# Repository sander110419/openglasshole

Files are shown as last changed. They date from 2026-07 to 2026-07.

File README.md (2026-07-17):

# OpenGlassHole

An open-source, clip-on, monocular heads-up autocue for ordinary prescription glasses.
It uses a tiny Wi-Fi microcontroller, a 64×32 white OLED, one positive lens, and
a separate 45° combiner pane to put scrolling server text at a comfortable
virtual distance. The reference optical path uses the OLED's central 48×32
pixels to trade two characters per line for a larger eye box.

OpenGlassHole optical path

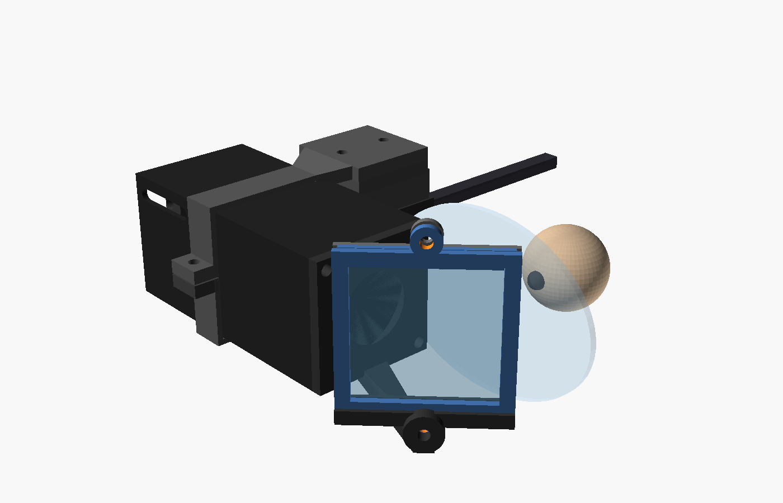
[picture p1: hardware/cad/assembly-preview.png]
OpenGlassHole right-eye CAD assembly preview


*CAD packaging preview, not a photograph or physical fit validation.*

> **Prototype status:** firmware, server, schematic, and parametric CAD are
> implemented and build-checked, but this v0.1 hardware has not yet been
> physically assembled or optically validated. Dimensions, runtime, eye box,
> and comfort are engineering targets until a real build report lands.

## The honest version

- **Budget-reference known cost:** **$46.59 USD** (prices checked 2026-07-17),
  using linked major parts and
  consumable allowances in [hardware/bom.csv](hardware/bom.csv). The exact
  splitter listing includes delivery; other shipping, tax, tools, and the cost
  of buying full fastener/strap/filament packs remain unresolved, so this does
  **not** prove a delivered-under-$50 first build.
- **Electronics:** Seeed XIAO ESP32-C3, USB-C, 2.4 GHz Wi-Fi, onboard 1S LiPo
  charger, protected PKCELL 500 mAh cell, and a 0.49-inch Waveshare SSD1315
  OLED.
- **Optics:** a 25 mm / 45 mm FL positive lens and a 30×30 mm 50R/50T plate
  combiner. The pane—not the prescription lens—reflects the cue. A measured
  6×6 mm full-cue eye box is a build acceptance requirement, not a promise.
- **Expected use:** seated, stationary, indoor autocue. It will wash out in
  sunlight and has a much smaller eye box than commercial waveguide glasses.
- **Power target:** roughly 18–29 hours with 15-second radio-off polling and
  sparse low-contrast text; about 4.2 hours is the conservative sustained
  worst-case estimate. Neither is a measured runtime yet.
- **Packaging:** the printed forward assembly's CAD envelope is about
  89.2×61.1×46.4 mm (the tunnel itself is 58.8×27.9×27.9 mm). With the optional
  rear pod on the glasses, the full envelope is about 113.5×120.3×46.4 mm. A
  preliminary all-on-glasses mass estimate is roughly 55–65 g; use the
  documented collar/pocket-pod option if that is uncomfortable. Neither mass
  nor comfort has been measured on a real build.

The focus sled, padded strap saddle, sliding rail, separate rear electronics
pod, left/right assembly previews, bench jig, and combiner cut template are
parametric. The OLED driver pre-mirrors text and handles the module's
nonstandard visible RAM-column offset.

## Safety first

This is uncertified DIY eyewear, not PPE or a medical device. Never use it while
driving, cycling, crossing roads, walking in traffic, using stairs, or operating
machinery. Charge the LiPo off-head and attended; never wear exposed prototypes.
The positive lens can concentrate sunlight, and every glass edge must be fully
captured. Read [the complete safety rules](docs/SAFETY.md) before ordering parts.

## How it works

```text
phone/browser ──PUT──> tiny Python cue server
                             │
                        conditional GET
                             │ Wi-Fi every ~15 s
                             ▼
                   XIAO ESP32-C3 ─I²C─> OLED
                                           │
eye <─ prescription lens <─ combiner <─ collimating lens
```

The server returns raw cue text plus `ETag`, poll, and scroll headers. Unchanged
cues return `304` with no body. The display caches the last valid cue, turns the
radio off between polls, word-wraps it to 8 characters × 4 rows, and
scrolls upward through network outages. The first and last views pause briefly
before the cue loops. Tap the one button to pause/resume; hold it to fetch
immediately.

## Build it

1. Read [SAFETY.md](docs/SAFETY.md), then inspect the
   [BOM](hardware/bom.csv) and [power assumptions](docs/POWER.md).
2. Wire the OLED over USB only using the
   [schematic](hardware/electronics/schematic.svg).
3. Copy `firmware/include/config.example.h` to the gitignored `config.h`, set
   Wi-Fi/server values, then build and flash with PlatformIO.
4. Run the dependency-free server:

   ```sh
   export OPENGLASSHOLE_API_KEY='replace-with-a-long-random-key'
   python3 server/cue_server.py --host 0.0.0.0 --port 8787
   ```

5. Print the fit coupon and focus jig. Prove focus and brightness on the bench
   before printing or wearing the clip.
6. Follow the [full build and alignment guide](docs/BUILD_GUIDE.md).

The browser editor is at `http://<server-lan-ip>:8787/`. The firmware consumes
`/api/v1/cue.txt?device=default`; see [API.md](docs/API.md) for automation.

## Repository map

| Path | Contents |
| --- | --- |
| [`firmware/`](firmware/) | PlatformIO XIAO firmware and custom 0.49-inch SSD1315 driver |
| [`server/`](server/) | Dependency-free Python cue API, editor, persistence, and tests |
| [`hardware/cad/`](hardware/cad/) | Parametric OpenSCAD, export tooling, and printable releases |
| [`hardware/electronics/`](hardware/electronics/) | Wiring schematic and assembly checks |
| [`hardware/bom.csv`](hardware/bom.csv) | Linked major parts, consumable allowances, and the <$50 calculation |
| [`docs/OPTICS.md`](docs/OPTICS.md) | Optical design, calculations, focus, and combiner tradeoffs |
| [`docs/BUILD_GUIDE.md`](docs/BUILD_GUIDE.md) | End-to-end print, wire, focus, mount, and test procedure |

## Validate the source

```sh
python3 -m unittest discover -s server/tests -v
python3 tools/check_bom.py
pio run --project-dir firmware
make -C hardware/cad check-release
python3 tools/check_repo.py
```

The software build does not prove optical focus, OLED brightness, battery
runtime, LiPo safety, fit, or comfort. A first physical build should record each
item in the acceptance checklist and the
[build-report template](docs/BUILD_REPORT_TEMPLATE.md) rather than silently
changing the design.

## Design references

- [Seeed XIAO ESP32-C3 dimensions, charging, pins, and power](https://wiki.seeedstudio.com/XIAO_ESP32C3_Getting_Started/)
- [Waveshare 0.49-inch SSD1315 OLED specifications](https://www.waveshare.com/0.49inch-oled-module.htm)
- [Espressif ESP32-C3 current specifications](https://documentation.espressif.com/esp32-c3_datasheet_en.pdf)
- [CERN Open Hardware Licence v2](https://cern-ohl.web.cern.ch/)

## License

Software is MIT licensed. Hardware, CAD, schematics, and build documentation are
licensed under CERN-OHL-P-2.0. See [LICENSE](LICENSE) for the exact scope and
notices. Third-party components and libraries retain their own licenses.

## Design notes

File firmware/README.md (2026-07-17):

# Firmware

This PlatformIO project targets the Seeed Studio XIAO ESP32-C3 and the exact
Waveshare 0.49-inch 64×32 SSD1315 I²C module used by the reference CAD.

## Flash it

1. Install [PlatformIO](https://platformio.org/install).
2. Copy `include/config.example.h` to `include/config.h`.
3. Set the Wi-Fi SSID/password and the cue server's LAN URL in `config.h`.
4. Connect the XIAO over USB-C and run:

   ```sh
   pio run --target upload
   pio device monitor
   ```

The display downloads `cue.txt` with a conditional HTTP GET, caches the last
valid cue in flash only when it changes, then word-wraps and scrolls it with the
radio off. The reference optical build uses the central 48 columns at the
reference 5×7 font size, so text wraps to 8 columns × 4 rows. Words wrap at
spaces, words longer than 8 characters split safely, and
explicit line/paragraph breaks are retained. Cues of four wrapped rows or less
remain centered and static. Longer cues hold the first view for 1.2 seconds,
move upward one pixel per `scroll_ms`, hold the final four rows for 1.8 seconds,
then loop back to the beginning.

Long-press the optional D2 button to fetch immediately; tap it to pause/resume
without stopping background fetches. A changed cue restarts at its first view.
Set `FETCH_ON_BOOT_ONLY=true` to fetch a prepared script once and reconnect only
on a long press.

The custom display driver matters: the Waveshare module exposes controller
columns `0x20..0x5f`. A generic 64×32 SSD1306 library that writes columns
`0..63` can compile successfully yet show a blank panel.

Plain HTTP is for a trusted LAN only. HTTPS requires a root CA, checks the
certificate chain/hostname, bounds the handshake, and sends a bearer value only
over TLS. The pinned Arduino-ESP32 build does **not** validate certificate dates,
however, so this is not a hardened public-internet client. Prefer a private LAN
or VPN and do not expose the bundled server directly.

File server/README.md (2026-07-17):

# Cue server

`cue_server.py` is a dependency-free Python 3.11+ threaded HTTP server with:

- a responsive browser cue editor at `/`
- minimal `GET /api/v1/cue.txt?device=...` responses with ETag/304 support
- JSON `GET` and authenticated text/JSON `PUT` endpoints
- per-device cues with fallback to `default`
- bounded inputs and atomic JSON persistence
- no API-key logging and no third-party package installation

Run on localhost for development:

```sh
OPENGLASSHOLE_API_KEY='development-only' python3 server/cue_server.py
```

Run on a trusted LAN for the glasses:

```sh
OPENGLASSHOLE_API_KEY='replace-with-a-long-random-key' \
  python3 server/cue_server.py --host 0.0.0.0 --port 8787
```

Test from the repository root:

```sh
python3 -m unittest discover -s server/tests -v
```

Read [the API and security model](../docs/API.md) before putting it on any
network other than a trusted LAN.

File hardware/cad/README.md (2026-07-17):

# OpenGlassHole CAD

This directory contains the parametric OpenSCAD 2021.01 source, reviewed STL
exports, and mechanical validation tools for the v0.1 monocular autocue. It is
a buildable optical/mechanical experiment, not certified eyewear. Prove the
optics on the bench before putting any part near an eye.

Wearable assembly preview with the optional rear pod hidden

## Presets and optical limits

`lens_preset="budget_25x45"` is the source and release-STL default:

- sourced 25 mm diameter, +45 mm focal-length biconvex acrylic lens;
- published 1.2 mm **edge** thickness, provisional 5 mm centre thickness and
  provisional, separately entered 1.90 mm crown sag on each face;
- explicit provisional packaging/focus-start datum 0.6 mm behind the front rim
  plane; this is not inferred from lens symmetry or claimed as a principal plane;
- 38–52 mm OLED focus travel, previewed at 45 mm;
- central 48×32 pixels of the 64×32 OLED (7.44×4.96 mm active viewport);
- conservative 15 mm physical aperture stop;
- 30×30×1.1 mm 50R/50T plate at 45 degrees, with 28 mm frame opening;
- 15 mm nominal lens-to-combiner axial gap and 32 mm bench eye datum.

`compact_23x30` remains available in source for experiments, but it is not a
recommended or release preset. At the same 32 mm eye datum its 10 mm stop and
wider field cannot provide a useful common full-viewport eye box. Do not buy the
more expensive compact lens on the assumption that it is a drop-in upgrade.

The SCAD computes the first-order extrema where the aperture/field rays meet an
oblique 45-degree pane. It also shifts the physical pane along its own axis to
centre that asymmetric footprint. For the budget preset the modeled footprint
is about 24.89 mm wide and the signed frame shift is about -1.03 mm, leaving
about 1.55 mm per side in the 28 mm opening. This calculation is deliberately
not presented as a guarantee: the physical stop is on the OLED side of a thick,
cheap singlet, and real principal planes, aberrations, decentre, and surface
tolerances matter. The focus bench and eye-box mapping are authoritative.

The modeled ray plane is the combiner's incoming/coated glass face, not the
printable base. The frame base is shifted 2.7 mm behind that face along the
pane normal, and each bracket/bench socket is centred on the complete 4.25 mm
base–glass–gap–clamp stack. This datum distinction prevents the plastic stack
from silently moving the reflected ray.

The best-case first-order common eye box at 15+32 mm propagation is only about
7.2 mm horizontal by 9.8 mm vertical for the budget preset. Treat that as an
optimistic estimate. Reject or redesign a build if the mapped eye box is not
comfortable; do not compensate by placing glass closer to the eye.

## Safe lens cell

The biconvex lens is not trapped between flat 15 mm rings. The tunnel has:

- full-diameter relief around both curved lens surfaces;
- three rear printed lands near the physical outer rim;
- three matching front lands on `lens_retainer` or `combiner_bracket`;
- a 15 mm tapered stop on the exterior/image-side front plate;
- a final 1.0 mm full-pocket counterbore before the compliant lands.

The SCAD takes `LENS_FRONT_SAG` and `LENS_REAR_SAG` as independent measured
inputs and derives a separate spherical envelope from each. The symmetric
1.90 mm defaults are provisional packaging data only. An asymmetric biconvex
lens may put most of its crown on either face. The stop-facing/image-side
**front** sag alone drives the analytic hard-gap check across the complete
taper; the rear sag alone drives the tunnel relief depth. The minimum need not
occur at the 15 mm aperture edge. With the provisional defaults, the true
minimum is about 1.012 mm at radius 11.036 mm for the budget lens and 0.855 mm
at radius 7.965 mm for the compact lens. Both exceed the asserted 0.6 mm
minimum, but neither is a guarantee for a purchased lens.

Before printing the final cell, measure the real lens in this order:

1. Measure diameter, centre thickness, and outer-rim edge thickness without
   squeezing the acrylic.
2. Support one rim plane on a depth-gauge fixture, measure its crown height,
   flip the lens, and independently measure the other crown height.
3. Confirm `edge + front sag + rear sag` agrees with centre thickness within
   the named 0.20 mm measurement allowance. Mark the face chosen to point at
   the retainer/combiner as **front/image-side** on removable rim tape.
4. Enter both measured sags and thicknesses, regenerate, and inspect the
   physical cell for at least 0.6 mm hard-surface clearance. The derived
   spherical surfaces are still approximations; the focus bench and a physical
   no-contact inspection are authoritative.

Put a matched nominal 0.7–0.8 mm closed-cell silicone, TPU, or optical-foam dot
on each of the six lands. Each opposing pair must exceed 1.2 mm uncompressed
(normally 1.4–1.6 mm total) and compress lightly into that modeled allowance;
reject a pair that rattles or requires plate bowing. Trim every dot so it
contacts only the outermost lens rim. Tighten the two front screws evenly only
until the dots prevent rattle. Printed plastic must never touch or preload
either convex clear surface.

## Combiner retention

Use the purchased square 30×30×1.1 mm glass plate as supplied. Do **not** score,
grind, chamfer, drill, or round the coated glass. The rounded/chamfered
`cut_template` is only for machinable plastic/film experiments or a professional
vendor-cut alternative. Mark coating orientation on removable frame tape, not
by modifying the pane.

The base's four overlapping full-length rails define a 32.0 mm rigid cavity;
they must never touch bare glass. Fit `combiner_edge_liner` around all four
edges and corners first. It is a one-piece **soft TPU or silicone** radial
collar with 29.8 mm free opening, 31.4 mm free outer size, 0.8 mm nominal wall,
and corner reliefs. Its 0.10 mm-per-side stretch gives a conservative 31.6 mm
fitted envelope, leaving 0.20 mm per side to the rails. Its 0.90 mm height is
recessed 0.10 mm from each glass face so it cannot become an axial clamp land.

Dry-fit the collar on the unmodified pane, covering every edge and corner.
Verify that it sits below both coated faces, then lower the pane and collar into
the frame together. Confirm soft material separates every glass edge from every
rigid rail; never force, abrade, score, or glue the pane. Only then add
`combiner_shim`, the separate 0.30 mm **soft TPU or foam face gasket**, inside
the rails. It compresses into the nominal 0.15 mm axial stack gap. Neither soft
part may be printed in rigid PETG/PLA.

The clamp uses two M2 through-bolts. Their head, nut, and washer envelope must
be no larger than 5.0 mm OD. After the modeled ±0.25 mm pane/liner motion and
±0.25 mm screw motion, the derived geometry preserves 1.05 mm to glass and
0.25 mm to the fitted liner. Put both heads on the clamp/outboard face and the
washer/nut on the base/bracket side. The wearable bracket positively captures
the complete lower ear with a rear boss; its shallow socket is alignment, not
safety retention. Tighten only until the face gasket prevents rattle; stop if
the frame bows or glass sees point pressure.

## Selectors

Set `part` in `openglasshole.scad` or pass `-D 'part="..."'`.

| Selector | Output | Purpose |
| --- | --- | --- |
| `assembly` | preview | Pupil-centred right/left wearable, real mount chain, pod, and chief ray. |
| `bench_assembly` | preview | Focus bench with the shifted combiner and nominal optics. |
| `focus_bench_jig` | printable | Canonical focus jig filename/selector. |
| `focus_bench` | printable | Backward-compatible alias for `focus_bench_jig`. |
| `oled_cartridge` | printable | Guided OLED bezel, cable relief, and focus-bolt hole. |
| `lens_tunnel` | printable | Support-free light tunnel, compliant rear lands, and focus slots. |
| `lens_retainer` | printable | Bench retainer with tapered surface relief and front pad lands. |
| `combiner_frame` | printable | Four-edge pane base with two M2 clearance ears. |
| `combiner_clamp` | printable | Matching two-screw clamp ring. |
| `combiner_shim` | soft printable/template | Compressible perimeter gasket; never rigid filament. |
| `combiner_edge_liner` | soft printable/template | Recessed, four-edge radial glass guard with corner reliefs. |
| `temple_saddle` | printable | Padded V saddle, two hook-and-loop strap stations, and rail. |
| `quick_release` | printable | Sliding carriage with side-access M2.5 rail lock. |
| `mount_adapter` | printable | Recessed/piloted cross adapter for staged assembly. |
| `engine_cradle` | printable | Lower split collar with clamp pilots. |
| `engine_clamp` | printable | Upper collar plus rearward/raised temple-offset arm. |
| `combiner_bracket` | printable | Lens-safe front plate, shifted pane socket, and bolted capture boss. |
| `rear_pod` | printable | Protected-cell/XIAO pod, external strap ears, USB/switch/cable openings. |
| `rear_pod_lid` | printable | Screwed lid with BTN1 reaction cage and FPC-antenna guides. |
| `rear_button_retainer` | printable | Slide-in wired-button backstop with open U-slot and pull tab. |
| `fit_coupon` | printable | Lens diameter, three pane slots, and rail fits. |
| `cut_template` | 2D DXF/SVG | Plastic/film/vendor-cut alternative only. |
| `cut_template_print` | printable | Physical plastic/film template; not a glass-working guide. |

`side` accepts `"right"` or `"left"` for the preview. Manufacturing parts are
not handed.

## Export and validation

Reviewed budget-preset meshes are tracked in [`stl/`](stl/). Local exports go
to ignored `build/` and are never silently overwritten:

```bash
cd hardware/cad
./export.sh fit_coupon stl
./export.sh lens_tunnel stl compact_23x30
./export.sh cut_template dxf
FORCE=1 ./export.sh fit_coupon stl
```

`OPENSCAD_BIN=/path/to/openscad` selects a custom executable; otherwise the
scripts try native OpenSCAD and then the Flatpak. The release-parity check is:

```bash
OPENSCAD_BIN=/path/to/openscad make validate
```

This renders every selector under both presets using OpenSCAD 2021 syntax,
rejects warnings/errors/empty output, then checks every STL for one connected
component, exactly two triangles per edge, and nonzero enclosed volume using the
dependency-free `validate_mesh.py`. It also proves that a rear-heavy asymmetric
lens still renders while the same large sag on the stop-facing front trips the
hard-gap assertion. To regenerate the tracked default meshes:

```bash
OPENSCAD_BIN=/path/to/openscad make release-stls
```

To prove tracked meshes have exactly the regenerated triangles (independent of
OpenSCAD facet ordering and winding) without changing them:

```bash
OPENSCAD_BIN=/path/to/openscad make check-release
```

## Printing and staged fasteners

Start with the fit coupon and focus bench. Suggested first settings are a
0.4 mm nozzle, 0.2 mm layers, three walls, and matte black PETG. Print the soft
combiner face gasket and edge liner separately in TPU, or cut/cast them from
suitable soft foam/silicone. Keep all optical interiors matte.

Orient the tunnel on its square lens end; OLED cartridge on its bezel; pod on
its closed floor; bench on its base. Put the `lens_retainer`'s **narrow 15 mm
stop face down**, so its aperture widens upward and its small front-pad
cantilevers remain self-supporting. Put the combiner rings on a flat face. The
offset `engine_clamp` normally prints with its top pad on the bed and the split
collar rising from it; inspect bridges and use localized support if your slicer
cannot bridge the arm.

Print `rear_button_retainer` flat on either broad face. Deburr its U-slot and
pull-tab edges without thinning the two side bearings.

`combiner_bracket` is a different one-piece shape: its socket/arm extends about
28 mm past the narrow stop plane, so that plane **cannot** sit on the bed. Put
the square tunnel-interface/full-pocket face (source `x=0`) on the bed with the
socket rising. Use removable, localized support from the build plate inside the
narrowing lens aperture and beneath the socket arm/capture boss. Keep support
off the three compliant-pad lands where possible. After removal, deburr without
enlarging the stop, confirm the 15 mm aperture and pad lands, and re-check at
least 0.6 mm hard clearance to the measured lens surface. If support cannot be
removed without scars or distortion in the cell, reject the print and split or
redesign the bracket; this part is not claimed to be support-free.

The modeled fastening order avoids inaccessible nuts:

| Qty | Fastener | Use |
| ---: | --- | --- |
| 2 | M2×5 socket head, head ≤4.4 mm OD ×2.0 mm high | adapter to carriage |
| 6 | M2×6 socket head | split collar (2), engine pad (2), lens plate (2) |
| 2 | M2×8 socket head | pod lid |
| 1 | M2×10 socket head | upper combiner ear |
| 1 | M2×12 socket head | bracket-captured lower combiner ear |
| 2 each | M2 washer ≤5.0 mm OD and M2 nyloc nut | both combiner ears |
| 1 | M2.5×6 socket head | carriage rail position lock |
| 1 | M2.5×35 bolt, two 8 mm OD washers, one M2.5 nyloc nut | focus lock |

1. Install two M2×5 socket-head screws (head OD ≤4.4 mm, height ≤2.0 mm)
   through the adapter's recessed X pair into the carriage's 3.5 mm blind
   pilots. The engine-pad relief accepts the remaining head projection.
2. Slide the carriage onto the saddle rail. Lock it from the exposed side with
   an M2.5×6 set screw; the carriage is a position lock, **not** a breakaway.
3. Fit the split collar around the tunnel using two M2×6 screws through the
   upper clearance flanges into the lower printed pilots.
4. Put the adapter under the raised offset pad. Insert two M2×6 screws from the
   pad's top Y pair into the adapter's printed pilots.
5. Use an M2.5×35 bolt, broad washers, and nyloc nut for the focus cartridge.
6. Use two short M2×6 screws for the lens-safe retainer/bracket, tightening the
   compliant dots evenly.
7. With heads on the clamp/outboard face, use one M2×12 bolt through the
   7.25 mm bracket-captured lower-ear stack and one M2×10 bolt through the
   4.25 mm upper-ear stack. Put a ≤5.0 mm OD, nominal 0.30 mm washer and an
   ordinary nominal 2.80 mm-high M2 nyloc on each base/bracket side. The source
   reserves another 0.80 mm for two full thread pitches beyond each locknut.
   Verify the actual stack and the worst-case glass/liner gaps before inserting
   the pane.
8. Use two M2×8 screws for the pod lid's external bosses.

Printed pilots are consumable. If repeated service loosens them, reprint or use
a deliberately resized heat-set insert design; do not improvise longer screws
where a battery or optical surface lies behind them.

## Bench and wearable reality

The v0.1 wearable uses a pupil-centred, same-height chief ray and a vertical
45-degree pane. It does not fake an unsupported raised reflection. The 50/50
pane therefore occupies the monocular sightline and is for seated, stationary,
indoor autocue testing only. The fixed bracket has no yaw/elevation gimbal.
Fore/aft travel comes from the rail; coarse placement comes from repositioning
the padded saddle straps. If on-frame alignment needs angular correction,
measure it and redesign/print a keyed wedge or gimbal before use.

The preview models a 2.5 mm minimum prescription-lens clearance and a rearward
top offset so the temple saddle remains near pupil height. Verify at least
2–3 mm under deliberate glasses-frame flex on the actual frame. Two separate
padded hook-and-loop bands are the intended snag release; the screwed carriage
and glass-frame bolt are not breakaways.

The optional rear pod is intentionally side-mounted: its inner body face is
tangent to the saddle's outboard face, while the nearest strap slot sits farther
outboard and each band bridges back to the temple. It is not centred on top of
the glasses arm. The preview derives its 100 mm temple proxy from both rear-pod
strap stations and asserts that each complete 6.5 mm band footprint lands on
the proxy. On real glasses, confirm both independent bands fully wrap the
temple and release under a snag before adding electronics.

The fixed OLED cartridge fits only the documented PCB orientation. If a loose
90-degree polarization test is better, swap the measured PCB/window Y/Z values
and reprint; the rectangular board cannot simply be forced into this cartridge.

The pod cavity models the protected 31×38×5.3 mm cell and a maximum
17.8×21×4.2 mm assembled XIAO/controller-and-connector envelope with a 3 mm end
gap. Battery guides leave 0.6 mm per side for removable soft padding. The lid
locates a provisional 18×8 mm supplied FPC antenna against plastic and keeps
the 6 mm BTN1 cage at least 5 mm from it. The cage bottom preserves a modeled
0.5 mm above that controller envelope; measure the tallest real board,
connector, solder, and wire feature and enlarge the pod if it exceeds 4.2 mm.

BTN1 must have an actuator at least 2.5 mm above its case so it projects at
least 0.9 mm above the 1.6 mm lid; a common short-stem switch is not operable
here. Install the wired switch from the lid underside, stem first, with its body
top against the lid and leads routed toward the cage's open `+Y` side. Slide
`rear_button_retainer` under the body from that side until its rear land stops;
the open U-slot lets the leads remain attached. The 0.8 mm plate bears on two
integral 0.85 mm ledges, providing the axial press reaction. Kapton may cross
the forked pull tab only as an anti-withdrawal/anti-rattle aid; it must not carry
button force, and glue is not a structural backstop. Remove that tape and pull
the plate out for switch service.

A local lip notch clears the nominal button body. Measure its body, stem, pin
exits, and lead bend before printing. Use the antenna adhesive plus Kapton, do
not cover its radiator with metal, and remove the lid for XIAO boot/reset
access. The USB-C, slide-switch, OLED-cable, and button openings still require
measurement against purchased parts.

Key release-mesh envelopes are 58.8×27.9×27.9 mm for `lens_tunnel`,
34.2×44.1×4.25 mm for the assembled printed combiner base/clamp stack before
hardware, 101.8×75×37.5 mm for the focus jig, and 46.3×66.4×13.5 mm for the
assembled rear pod and lid including external ears. At the nominal right-eye
placement, the forward printed assembly's axis-aligned envelope is
89.18×61.10×46.35 mm; mounting the optional rear pod as previewed expands that
to 113.48×120.30×46.35 mm. The rear pod can instead move to a pocket or collar
without changing the optical engine.

## Mass and placement

For the budget preset, modeled worn printed volume, including both soft
combiner parts and the button retainer, is 32.58 cm³:

| Group | Volume | Solid PETG equivalent (1.27 g/cm³) |
| --- | ---: | ---: |
| Forward optics + saddle/mount | 21.65 cm³ | 27.5 g |
| Rear pod + lid + button retainer | 10.93 cm³ | 13.9 g |
| Total worn printed geometry | 32.58 cm³ | 41.4 g |

A three-wall/25%-infill slice is still dominated by thin shells; record the
slicer's actual estimate instead of multiplying the solid equivalent by 25%.
With glass, lens, cell, boards, wire, straps, and fasteners, a complete
glasses-mounted prototype is more realistically around 55–65 g, not 30–35 g.
Move the rear pod and battery to a pocket/collar pack if comfort or frame load
is unacceptable; that removes about 13.9 g of printed pod parts plus the rear
electronics/cell from the glasses. The focus jig and fit coupon add 50.95 cm³
(64.7 g solid-PETG equivalent) but are calibration tools, not worn mass.

Never wear while charging. Never drive, cycle, walk in traffic, or perform a
safety-critical task with the pane in view. Keep the assembly away from direct
sunlight: a positive lens can concentrate solar energy onto the OLED or nearby
material.

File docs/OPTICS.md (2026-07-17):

# Optics: what makes the text focusable

The inexpensive, buildable path is a tiny projector and a separate combiner:

```text
OLED → positive lens → 45° partial reflector → prescription lens → eye
```

It does **not** project text onto the prescription lens. The positive lens makes
the OLED rays approximately parallel; the eye then perceives a virtual image at
a comfortable distance while still seeing the world through the partially
reflective pane. Ordinary prescription lenses are unreliable reflectors because
their angle, curvature, and anti-reflective coatings vary. Never apply film to
them.

Top-view optical path

## Reference geometry

The CAD defaults are packaging values that must be tuned to the parts in hand:

| Parameter | Reference value |
| --- | ---: |
| OLED controller/module | SSD1315, 64×32, 15.5×13 mm board |
| Emitting raster | approximately 9.92×4.96 mm from 0.155 mm pixel pitch |
| Lens | biconvex acrylic, 25 mm diameter, nominal 45 mm EFL; measure edge/centre thickness and both face sags |
| Lens clear stop | 15 mm image-side tapered aperture; retention stays at the padded outer rim |
| OLED-to-lens travel | 38–52 mm |
| Combiner | 30×30×1.1 mm, 50R/50T plate |
| Lens-to-combiner gap | 15 mm nominal |
| Combiner-to-pupil distance | 32 mm nominal |
| Combiner pose | fixed nominal 45° yaw; calibrate the whole mount |
| Normal position | chief ray centred on the chosen pupil; pane occupies that eye's sightline |

The panel is 64×32, but the reference firmware deliberately lights only the
central 48×32 raster: roughly 7.44×4.96 mm. With the budget lens's 45 mm
thin-lens focal length, its first-order field is:

```text
horizontal FOV = 2 atan(7.44 / (2 × 45)) ≈ 9.5°
vertical FOV   = 2 atan(4.96 / (2 × 45)) ≈ 6.3°
```

The 45° pane makes the beam footprint asymmetric. Intersecting the two extreme
horizontal field rays with the modeled pane gives a roughly 24.9 mm footprint,
shifted about 1.0 mm from the chief-ray intersection. The CAD shifts the frame
to centre that bundle in its 28 mm clear aperture, leaving about 1.55 mm at
each modeled edge. This is a first-order packaging check, not proof: the cheap
singlet will still have edge blur, distortion, stop-thickness effects, and tight
alignment tolerances.

## Eye box and the intentional crop

For an axis-only first-order check, the common full-image pupil overlap is
approximately. The calculation deliberately uses a conservative 47 mm path
(15 mm nominal lens-to-pane plus 32 mm pane-to-pupil); the physical image-side
stop sits slightly closer to the pane.

```text
eye-box axis ≈ stop diameter − 2 × (stop-to-pupil path) × tan(half field)
horizontal   ≈ 15 − 2 × 47 × (7.44 / 90) ≈ 7.2 mm
vertical     ≈ 15 − 2 × 47 × (4.96 / 90) ≈ 9.8 mm
```

That estimate ignores field corners, eye rotation, lens aberration, assembly
error, and prescription-lens effects. The build guide therefore sets a lower
measured acceptance threshold of **6×6 mm** for the whole cropped cue. If it
misses, do not call the wearable complete: re-align on the bench or use a
larger matched lens and combiner. Restoring all 64 columns with this 30 mm pane
shrinks the margin too far for the reference design.

The CAD retains a 23 mm / 30 mm short-focus preset for experiments only. With
its 10 mm stop, it has no positive first-order horizontal overlap for the whole
48-column cue at the reference eye relief. It is not a release build or BOM
alternative.

## Focus is a calibration, not a fixed dimension

Effective focal length is measured from a lens principal plane, not necessarily
from its outer surface. Back focal length (BFL), edge thickness, independently
measured front/rear crown sag, and low-cost part tolerances all matter. A
biconvex label does not prove equal faces. The CAD therefore takes both sags as
explicit inputs and treats its focus-start datum as provisional; that is why the
budget OLED cartridge moves 14 mm.

1. Measure the lens, including each face sag from its own rim plane, and the
   OLED; then update the top-level CAD parameters. The entered front face is the
   image-side/stop-facing surface.
2. Build the focus jig before the wearable mount.
3. Start with the OLED emitting plane at the supplier's BFL. If only EFL is
   known, start slightly inside that distance and use the full adjustment range.
4. Place a camera at the intended eye point, set manual focus to infinity, and
   aim through the combiner at a distant scene.
5. Move the OLED until both the cue and distant scene are acceptably sharp
   without refocusing the camera. Lock the sled.
6. Only then do a brief seated human alignment test with all glass edges covered.

For a plano-convex lens, start with the plano face toward the OLED and curved
face toward the collimated side. A genuinely symmetric biconvex lens has no
preferred face. If the cheap biconvex part is asymmetric and either orientation
focuses acceptably, the shallower crown toward the image-side stop provides
more mechanical clearance; always enter the two sags in their installed order.

## Combiner choices

- **Reference:** 30×30 mm, roughly 50% reflection / 50% transmission plate
  specified near 45°. It prioritizes cue brightness for indoor use.
- **Higher see-through:** 30R/70T teleprompter material. The world is brighter,
  but the cue is dimmer.
- **Cheapest experiment:** 0.5–1 mm clear PET/polycarbonate plus HUD reflective
  film. It is safer and easy to cut, but often creates a double image.
- **Plain clear sheet:** only a few percent reflection and usually useful only
  in a dim room.

Put a coated splitter face toward the incoming OLED beam to suppress the second
surface ghost. Do not FDM-print the optical pane. Use the cut template only for
plastic/film experiments. Never cut, drill, grind, or round the sourced coated
glass; keep its vendor-finished shape. Fit the one-piece recessed soft radial
edge collar before lowering the pane into the rigid frame, then add the separate
soft face gasket. Fully capture all four edges/corners and handle coated faces
only by their edges.

An optional opaque flag behind the pane gives much better contrast in a bright
room and allows lower OLED power. It makes the display temporarily occluded,
which is acceptable for a stationary autocue but not an AR illusion.

## Prescription and polarization checks

Test through the exact glasses. Strong curvature, progressive zones, prism,
tints, and coatings can change focus or alignment. OLED light is polarized;
polarized sunglasses may make it dim or disappear at one orientation. Rotate the
loose OLED module 90° during the bench test. The fixed reference cartridge does
not fit the rotated rectangular board; if that orientation wins, swap the
measured PCB/window axes in the CAD and print a matching cartridge.

## Primary references

- [Waveshare 0.49-inch OLED dimensions and pixel pitch](https://www.waveshare.com/0.49inch-oled-module.htm)
- [Edmund Optics focal length and field-of-view relationship](https://www.edmundoptics.com/knowledge-center/application-notes/imaging/understanding-focal-length-and-field-of-view/)
- [Edmund Optics lens geometry and PCX orientation](https://www.edmundoptics.com/knowledge-center/application-notes/optics/understanding-optical-lens-geometries/)
- [Thorlabs plate beamsplitter construction and rear-surface reflection](https://www.thorlabs.com/NewGroupPage9_PF.cfm?ObjectGroup_ID=4808)

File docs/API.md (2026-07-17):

# Cue API

The bundled server has no third-party dependencies. It serves a browser editor,
one tiny text response for the glasses, and a JSON update endpoint.

## Run it

From the repository root:

```sh
export OPENGLASSHOLE_API_KEY='choose-a-long-random-update-key'
python3 server/cue_server.py --host 0.0.0.0 --port 8787
```

Open `http://<computer-lan-ip>:8787/` on a phone or laptop. Do not expose this
development server directly to the public internet. Binding `0.0.0.0` makes it
reachable on local interfaces; use a trusted LAN and firewall.

## Display read

```http
GET /api/v1/cue.txt?device=default HTTP/1.1
If-None-Match: "1-0d9f..."
```

A changed cue returns raw UTF-8 text, including normalized line breaks. The
server preserves Unicode for future display fonts, but the v0.1 firmware's 5×7
font renders printable ASCII only and replaces each non-ASCII code point with
`?`. The reference firmware word-wraps to 8 columns × 4 visible rows:

```http
HTTP/1.1 200 OK
Content-Type: text/plain; charset=utf-8
ETag: "2-79e4..."
Cache-Control: no-cache
X-Poll-Seconds: 15
X-Scroll-Ms: 65

Welcome to
the next section
```

An unchanged cue returns `304 Not Modified` with no body. This minimizes radio
airtime and allocation on the ESP32. `GET /api/v1/cue?device=default` returns
the same state as JSON for tools.

Unknown device names fall back to the `default` cue. Once a device-specific cue
is written, it has independent state. Names are limited to 1–64 ASCII letters,
digits, dots, dashes, or underscores.

## Update

Raw text:

```sh
curl --request PUT \
  --header 'X-API-Key: choose-a-long-random-update-key' \
  --header 'Content-Type: text/plain; charset=utf-8' \
  --data-binary 'Camera two. Slow down.' \
  'http://127.0.0.1:8787/api/v1/cue?device=default'
```

JSON can also update timing:

```json
{
  "text": "Camera two.\n\nSlow down.",
  "poll_seconds": 15,
  "scroll_ms": 65
}
```

Limits are 512 normalized cue characters, 2–3600 seconds between polls, 25–500
milliseconds per vertical scroll pixel, and 4096 request bytes. Within each
line, whitespace is collapsed and trimmed; explicit line breaks are retained,
while repeated blank lines collapse to one paragraph gap. The firmware wraps at
spaces, splits words longer than 8 columns, holds the first view for 1.2
seconds, holds the last view for 1.8 seconds, and then loops. Four wrapped rows
or fewer are centered without scrolling. Cue state is atomically persisted to
`server/data/cues.json` by default.

## Security model

- `OPENGLASSHOLE_API_KEY` protects writes, not reads. An autocue is normally on
  a private stage/home LAN and keeping display reads simple saves configuration.
- Without the environment variable, writes are unauthenticated and the editor
  shows a warning.
- Do not publish this server directly. If remote control is unavoidable, put it
  behind a maintained HTTPS reverse proxy or private VPN and authenticate reads
  as well as writes. The pinned firmware checks CA chain and hostname but not
  certificate validity dates, so treat its HTTPS support as defense in depth,
  not as a hardened public-internet client.
- Wi-Fi credentials, tokens, and private certificates belong in
  `firmware/include/config.h`, which is gitignored.

## Other endpoints

| Endpoint | Purpose |
| --- | --- |
| `GET /` | Same-origin cue editor |
| `GET /healthz` | `{"status":"ok"}` liveness check |
| `GET /api/v1/cue` | JSON cue state |
| `GET /api/v1/cue.txt` | Minimal firmware response |
| `PUT /api/v1/cue` | Authenticated cue update |

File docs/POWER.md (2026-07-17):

# Power design and battery-life expectations

The reference design removes the radio from the hot path: it associates with
Wi-Fi, makes one conditional GET, turns Wi-Fi off, and scrolls the cached cue.
The server returns `304 Not Modified` when nothing changed. The ESP32 still has
to redraw the word-wrapped vertical scroller one pixel at a time, so this is not
deep-sleep operation.

Seeed publishes the following XIAO ESP32-C3 board figures: 75 mA active Wi-Fi,
25 mA modem sleep, 4 mA light sleep, 44 µA deep sleep, and a 380 mA charge
current. These are useful bounds, not a finished-device measurement. The OLED,
regulator loss, signal quality, association time, brightness, and lit-pixel
count change the result.

Use this deliberately conservative estimate:

```text
usable runtime hours ≈ battery mAh × 0.8 / measured average mA
```

The 0.8 factor allows for cell ageing, regulator dropout, temperature, and
optimistic capacity labels.

| Operating mode | Estimated average | 500 mAh estimate |
| --- | ---: | ---: |
| Worst sustained Wi-Fi + bright/all-pixel OLED | ~95 mA | ~4.2 h |
| Always connected, modem power-save | ~36 mA | ~11 h |
| Reference 15 s radio-off polling | ~14–22 mA | ~18–29 h |
| `FETCH_ON_BOOT_ONLY`, radio off during playback | ~8–16 mA | ~25–50 h |

Only the worst-case bound comes directly from adding published component-scale
figures. The other rows are engineering targets. Do not advertise a runtime
until it is measured on the assembled device.

## Measuring the real build

1. Fully charge the cell off-head.
2. Put a current/power logger in series with the battery; a USB meter mostly
   measures the charger and is misleading when the battery is attached.
3. Measure at least five minutes in each mode: scrolling offline, successful
   poll, failed server, failed Wi-Fi, always-connected, display blank, and max
   brightness.
4. Record Wi-Fi RSSI, poll interval, OLED contrast, cue pixel density, battery
   voltage, and firmware commit.
5. Integrate current over a full hour. Short transmit peaks can exceed 300 mA,
   so an average-only multimeter is not enough to validate wiring stability.
6. Update `hardware/power_budget.csv` with measured values and keep estimates
   clearly labelled.

## Easy ways to extend runtime

- Increase the poll interval from 15 to 30–60 seconds when instant updates are
  unnecessary.
- Keep `RADIO_OFF_BETWEEN_POLLS = true`.
- Reduce `OLED_CONTRAST`; OLED load depends strongly on lit pixels.
- Keep cue glyphs sparse and use a black background.
- Fetch a complete short script and use the button to reload between sections.
- Use a physical switch for true off. Base-board deep sleep does not help much
  if the OLED remains powered.

The XIAO's 380 mA charger is within the documented protected PKCELL reference
cell's 500 mA maximum charge rate. That cell is also specified for 500 mA
continuous discharge. Do not substitute a smaller or undocumented cell without
checking both ratings.

## Primary references

- [Seeed XIAO ESP32-C3 power and charge specifications](https://wiki.seeedstudio.com/XIAO_ESP32C3_Getting_Started/)
- [Espressif ESP32-C3 datasheet current tables](https://documentation.espressif.com/esp32-c3_datasheet_en.pdf)
- [PKCELL protected 500 mAh LiPo specifications and dimensions](https://www.tinytronics.nl/en/power/batteries/li-po/pkcell-li-po-battery-3-7v-500mah-jst-ph-lp503035)
- [Adafruit LiPo protection and handling guidance](https://learn.adafruit.com/li-ion-and-lipoly-batteries/protection-circuitry)

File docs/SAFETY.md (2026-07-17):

# Safety

OpenGlassHole is an uncertified DIY electronics and optics prototype. It is not
protective eyewear, a medical device, or a certified head-mounted display.

## Never use it in motion-critical situations

Do not wear or read it while driving, cycling, crossing roads, walking in
traffic, using stairs, operating machinery, playing sport, or doing anything
where an obstructed field of view or distraction could injure someone. Test it
seated and stationary. The reference 50/50 combiner occupies one eye's normal
sightline and deliberately dims that view; keep the other eye unobstructed. Use
padded hook-and-loop straps that can pull free under a snag; the printed sliding
carriage itself is not a certified breakaway.

## Eye and optical hazards

- Use the lowest comfortable OLED contrast and take regular breaks. Stop for
  eyestrain, headache, nausea, double vision, or difficulty refocusing.
- Do not look at the sun, lasers, or intense light sources through the optics.
- A positive lens can focus sunlight onto the OLED or housing. Fit the opaque
  storage cover and never leave the optical engine facing direct sun.
- The display is not sunlight-readable; a washed-out cue is a reason to stop,
  not to raise brightness indefinitely.
- Fully capture every combiner edge/corner inside the recessed soft radial
  collar, with a separate soft face gasket preventing axial rattle. No bare
  glass may touch a rigid rail or fastener. Never cut,
  drill, grind, or round the sourced coated glass. Apply safety film only if the
  pane vendor permits it and never to the coated face. Polycarbonate is safer
  to fabricate but often has worse ghosting.
- Keep at least 2–3 mm dynamic clearance from prescription lenses. Do not glue,
  tape, or apply reflective film to prescription lenses or coatings.
- The clip must release under a snag and contain no sharp fastener near the eye.
- A collar/pocket pod needs a low-retention inline disconnect near the glasses;
  never leave a body-tethered cable able to pull the frame into the eye.

## LiPo and electrical hazards

- Use only a protected 1S LiPo with a documented charge rating of at least
  380 mA and continuous discharge rating of at least 500 mA. Validate the
  finished build through Wi-Fi current peaks before wearing it.
- Confirm polarity with a multimeter. JST and pigtail polarity is not universal.
- Put the cell in the rigid rear pod with strain relief. Never screw through,
  crush, fold, bend, or tightly clamp a pouch cell.
- Charge off-head, at room temperature, on a nonflammable surface, and while
  attended. In the reference wiring the power switch must be ON to charge.
- Stop immediately if the cell becomes hot, swollen, soft, creased, punctured,
  smells unusual, or has damaged wiring. Move it away from flammables only if
  that can be done safely and follow local battery-disposal rules.
- Do not wear an unfinished breadboard build or exposed conductors near the face.

Build and use this project at your own risk. The source is provided without a
warranty; see the repository licenses.

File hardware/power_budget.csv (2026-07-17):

mode | estimated_average_mA | usable_500mAh_hours | assumptions
Worst case sustained | 95 | 4.2 | 75 mA board active Wi-Fi plus about 20 mA all-pixel OLED; conservative lower bound
Always connected live polling | 36 | 11.1 | Maximum modem sleep, short polls, sparse OLED around 6 mA
Reference radio-off polling | 18 | 22.2 | 15 s conditional GET, radio off between polls, software vertical scroller, sparse dim OLED
Optimized script cached locally | 12 | 33.3 | Fetch once, radio off during playback, modeled sparse low-brightness text

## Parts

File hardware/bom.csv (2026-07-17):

item | qty | required | part_or_spec | example_source | unit_usd | extended_usd | notes
MCU1 | 1 | yes | Seeed Studio XIAO ESP32-C3 | https://www.seeedstudio.com/Seeed-XIAO-ESP32C3-p-5431.html | 4.99 | 4.99 | USB-C, Wi-Fi, 380 mA 1S charger
DISP1 | 1 | yes | Waveshare 0.49in OLED, 64x32, SSD1315, white, SKU 26783 | https://www.waveshare.com/0.49inch-oled-module.htm | 5.99 | 5.99 | Includes MX1.25 four-wire cable
LENSB | 1 | yes | Budget reference: 25 mm diameter / 45 mm focal-length biconvex acrylic lens | https://pgi-shop.de/en/acrylglas-linse-oe-25-mm-f-45-mm/ | 1.72 | 1.72 | EUR 1.50 converted at 1 EUR = 1.1467 USD; available on 2026-07-17; shipping unresolved
COMB1 | 1 | yes | 30x30x1.1 mm 50R/50T plate beamsplitter specified at 45 degrees | https://www.ebay.com/itm/353187332336 | 18.89 | 18.89 | Active exact-size listing showed free worldwide shipping on 2026-07-17; marketplace availability changes
BAT1 | 1 | yes | Protected PKCELL LP503035 1S 3.7 V 500 mAh LiPo | https://www.tinytronics.nl/en/power/batteries/li-po/pkcell-li-po-battery-3-7v-500mah-jst-ph-lp503035 | 5.45 | 5.45 | EUR 4.75 converted at 1 EUR = 1.1467 USD; 11 g, max 38x31x5.3 mm, 500 mA charge/discharge; listed 2-4 weeks on 2026-07-17
SW1 | 1 | yes | Mini SPST slide switch rated >=1 A DC | generic | 0.40 | 0.40 | Switch is ON while charging in the reference wiring
BTN1 | 1 | yes | 6 mm normally-open long-stem momentary push button | generic | 0.15 | 0.15 | Measure body/stem before printing; actuator must protrude through the closed lid
WIRE1 | 1 | yes | 30 AWG silicone wire, heat-shrink, battery pigtail | generic | 1.50 | 1.50 | Verify battery polarity with a multimeter
FAST1 | 1 | yes | 2x M2x5 low-head, 6x M2x6, 2x M2x8, 1x M2x10, 1x M2x12, 1x M2.5x6, 1x M2.5x35, washers and nyloc nuts | generic | 2.00 | 2.00 | M2x5 heads <=4.4 mm OD x 2.0 mm high; two combiner washers <=5.0 mm OD and ordinary M2 nylocs about 2.8 mm high; trim printed pilots; no screw may bear on the battery, optics, or glasses
STRAP1 | 4 | yes | 6-8 mm reusable hook-and-loop strap | generic | 0.25 | 1.00 | Two bands for the padded temple saddle and two for the on-glasses rear pod
PAD1 | 1 | yes | 1 mm TPU or silicone grip pad | generic | 0.50 | 0.50 | Protects the glasses frame
RETAIN1 | 1 | yes | Thin closed-cell foam and Kapton tape scraps | generic | 0.20 | 0.20 | Removable OLED retention and insulation; no pressure on the display glass
EDGE1 | 1 | yes | Soft 0.8 mm radial TPU or silicone combiner edge collar and optional vendor-compatible safety-film scrap | generic | 0.35 | 0.35 | Use the one-piece liner pattern to cover all four edges/corners below both coated faces; never substitute rigid PETG/PLA; apply film only if the pane vendor permits it
GROM1 | 1 | yes | Soft cable grommet / strain-relief scrap | generic | 0.15 | 0.15 | Protects OLED and battery wiring at housing exits
BLACK1 | 1 | yes | Matte-black paint or flocking-tape scrap | generic | 0.30 | 0.30 | Suppresses internal reflections; keep off every optical surface
PRINT1 | 1 | yes | Black PETG filament allowance, approximately 150 g | local print | 3.00 | 3.00 | Covers the reference calibration and wearable parts at about USD 20/kg; slicer use and failed prototypes vary
FLAG1 | 1 | no | Removable opaque black card/foam storage and contrast flag | generic | 0.25 | 0.25 | Improves indoor contrast and covers the positive lens during storage; do not attach to optical coatings
DISC1 | 1 | no | Low-retention four-pin inline cable connector | generic | 0.40 | 0.40 | Recommended for a collar/pocket pod; prove off-head that it disconnects under cable pull
MOS1 | 1 | no | AO3401A P-channel MOSFET plus 100k/10k resistors | generic | 0.30 | 0.30 | Optional OLED hard-off for deep standby

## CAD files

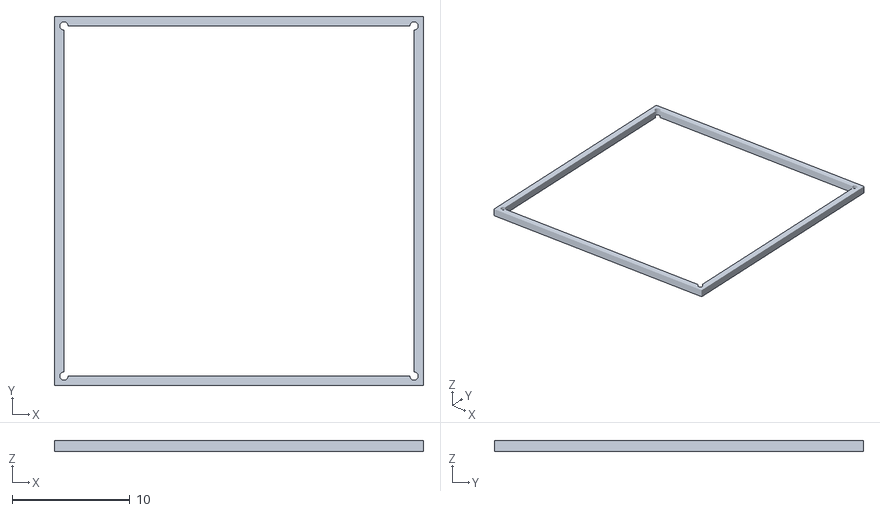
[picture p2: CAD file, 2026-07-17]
hardware/cad/stl/combiner_edge_liner.stl
31.4 x 31.4 x 0.9

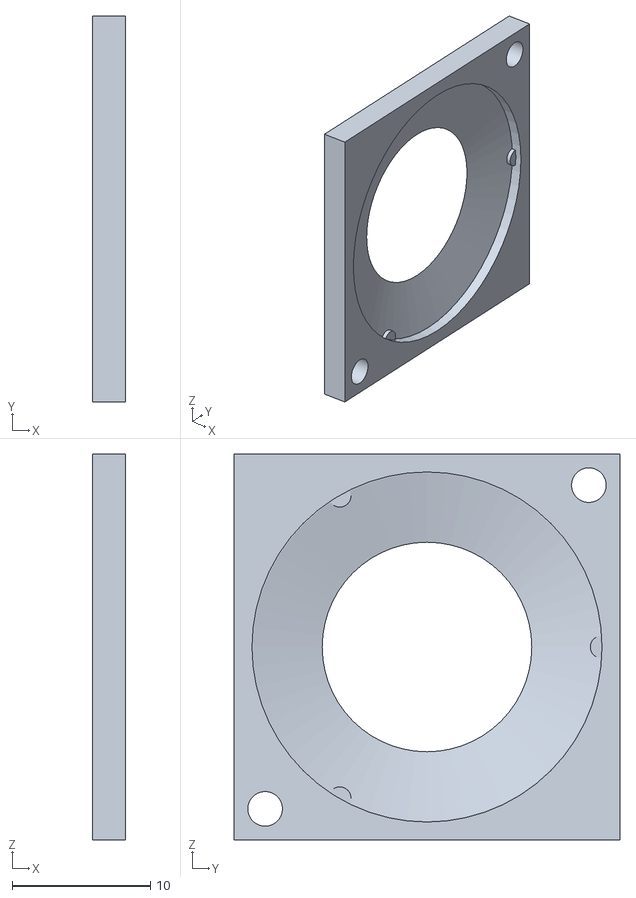
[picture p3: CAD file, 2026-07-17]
hardware/cad/stl/lens_retainer.stl
2.40 x 27.9 x 27.9

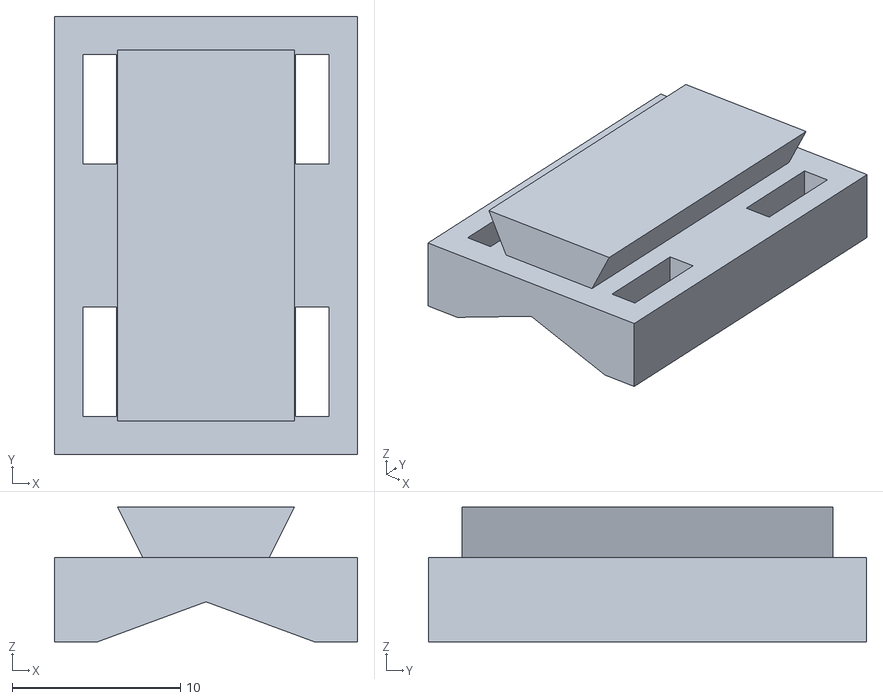
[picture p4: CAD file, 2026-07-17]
hardware/cad/stl/temple_saddle.stl
18.0 x 26.0 x 8.00

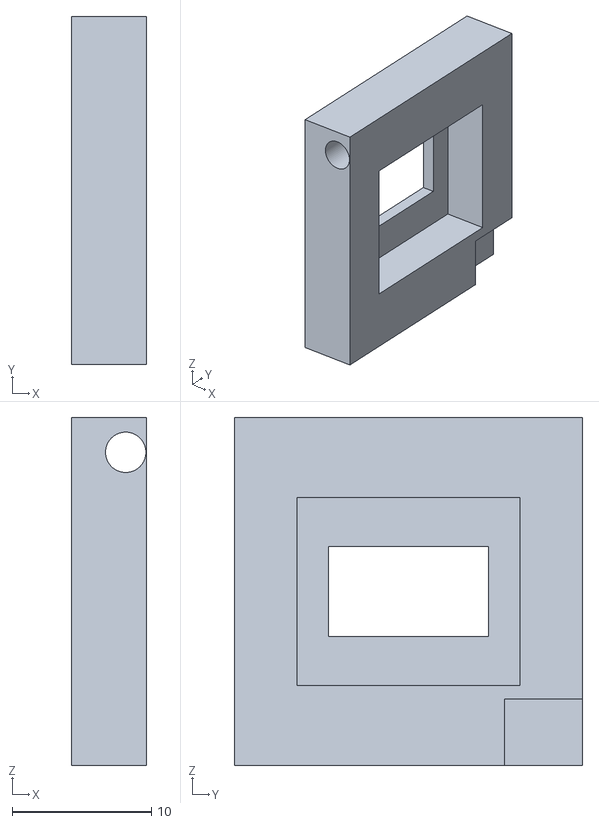
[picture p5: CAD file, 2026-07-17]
hardware/cad/stl/oled_cartridge.stl
5.40 x 25.0 x 25.0

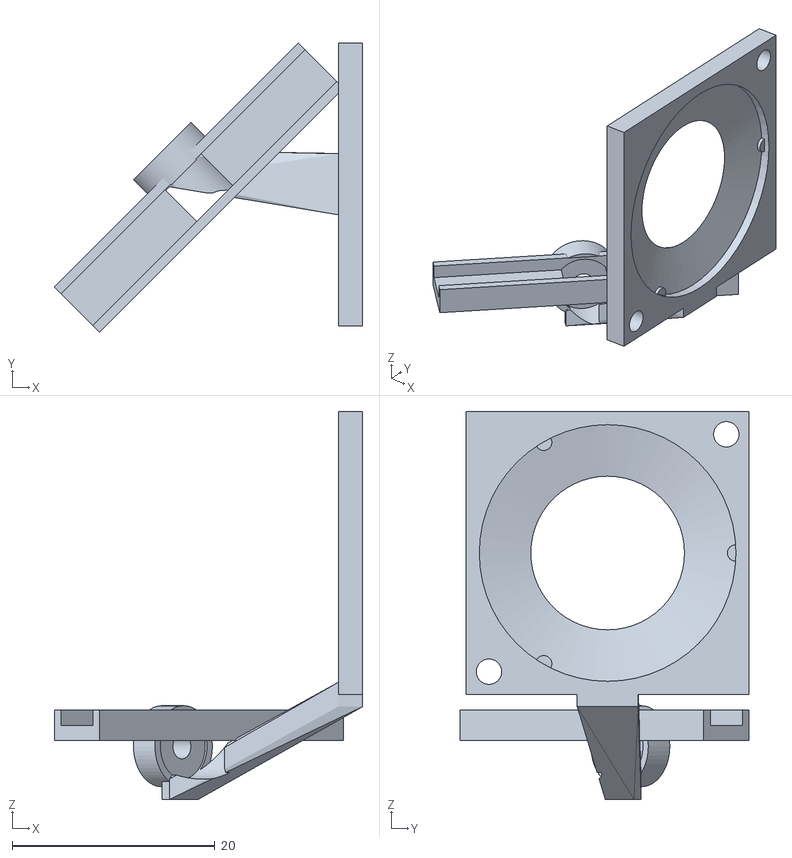
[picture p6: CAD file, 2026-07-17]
hardware/cad/stl/combiner_bracket.stl
30.4 x 28.5 x 38.2

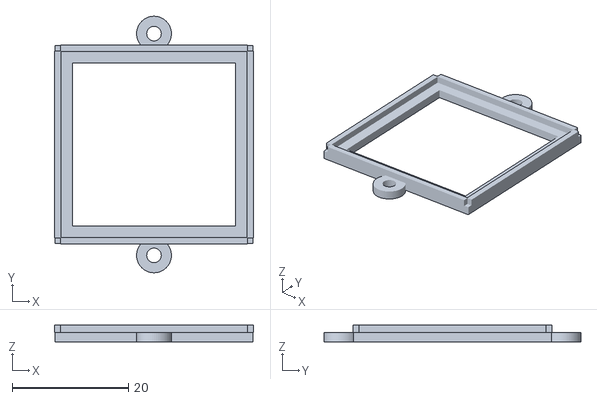
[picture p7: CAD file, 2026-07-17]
hardware/cad/stl/combiner_frame.stl
34.2 x 44.1 x 2.85

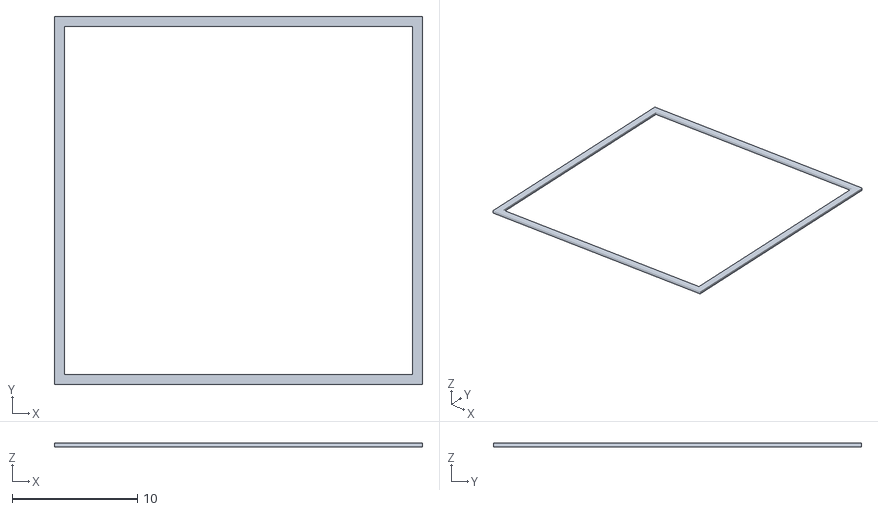
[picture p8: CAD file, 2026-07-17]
hardware/cad/stl/combiner_shim.stl
29.4 x 29.4 x 0.3

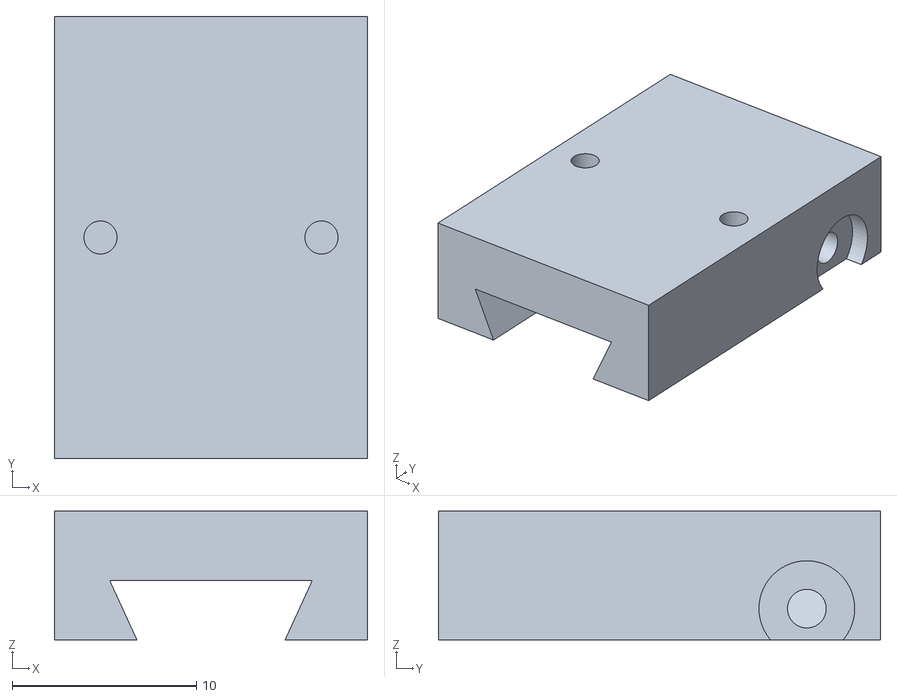
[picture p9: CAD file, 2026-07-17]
hardware/cad/stl/quick_release.stl
17.0 x 24.0 x 7.00

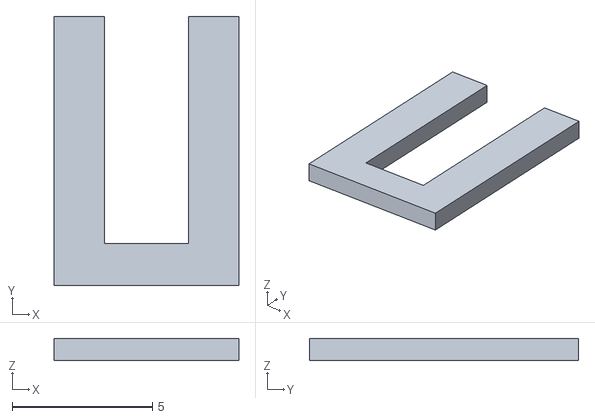
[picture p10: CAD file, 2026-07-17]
hardware/cad/stl/rear_button_retainer.stl
6.60 x 9.60 x 0.8

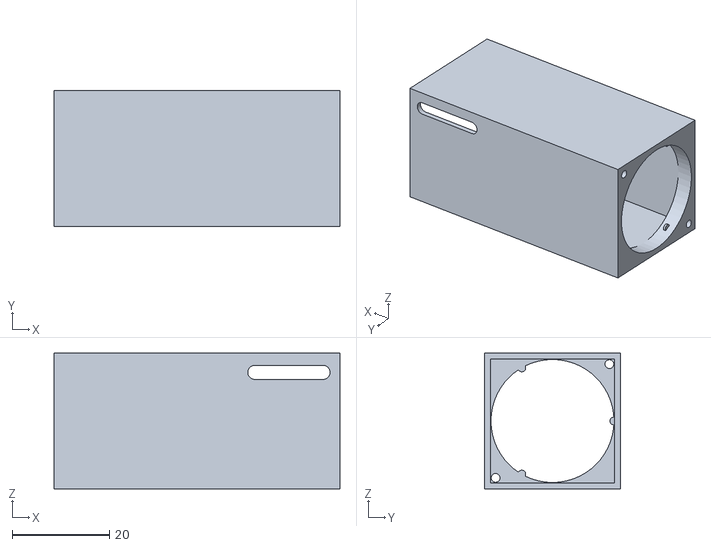
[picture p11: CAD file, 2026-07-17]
hardware/cad/stl/lens_tunnel.stl
58.8 x 27.9 x 27.9

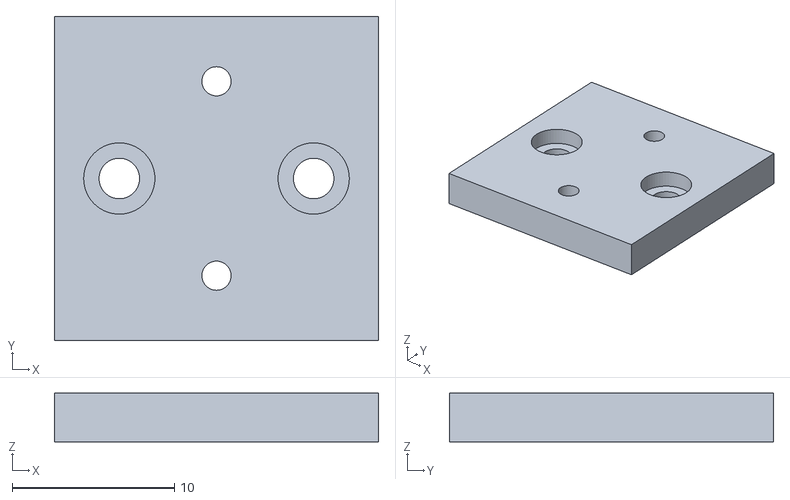
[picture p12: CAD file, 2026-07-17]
hardware/cad/stl/mount_adapter.stl
20.0 x 20.0 x 3.00

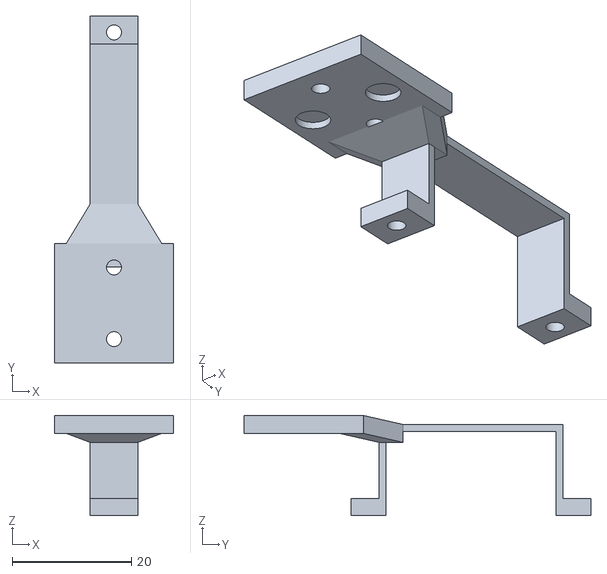
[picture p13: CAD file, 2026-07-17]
hardware/cad/stl/engine_clamp.stl
20.0 x 58.1 x 16.8

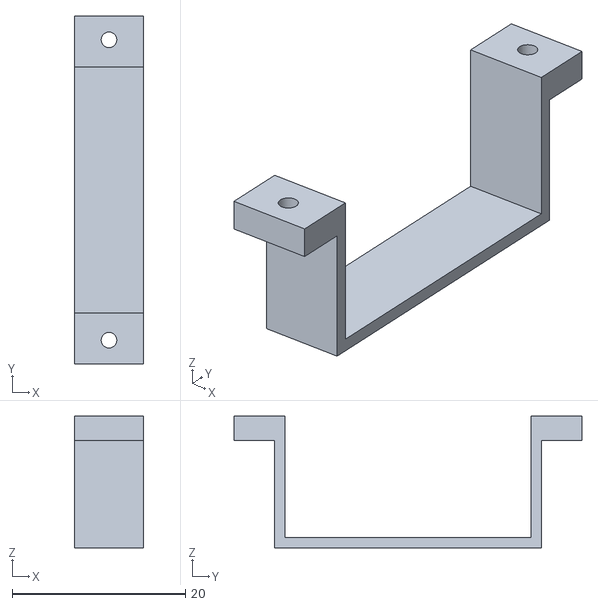
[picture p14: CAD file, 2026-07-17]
hardware/cad/stl/engine_cradle.stl
8.00 x 40.2 x 15.2

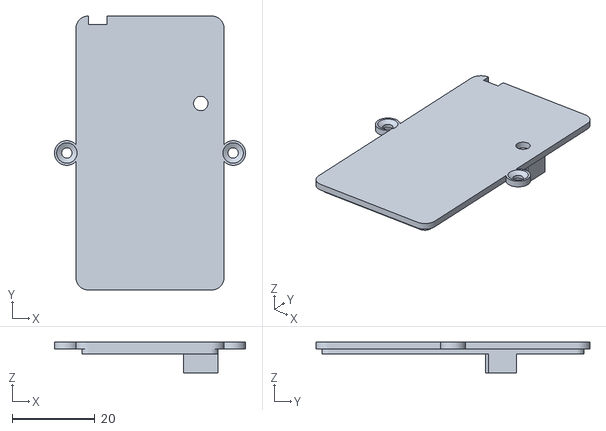
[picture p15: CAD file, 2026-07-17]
hardware/cad/stl/rear_pod_lid.stl
46.3 x 66.4 x 7.40

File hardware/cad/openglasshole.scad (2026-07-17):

/*
 * OpenGlassHole v0.1 mechanical reference
 *
 * Units: millimetres.
 * Axes in the assembly preview:
 *   +X = wearer's right, +Y = forward, +Z = up.
 * The optical engine itself is modelled along +X: light leaves the OLED,
 * travels toward -X through the lens, then turns toward the eye at the
 * 45-degree combiner.
 *
 * This is packaging CAD, not an optical ray tracer. Print the fit coupon and
 * focus bench before committing to the wearable parts. Measure every sourced
 * component and override the top-level parameters as needed.
 */

$fn = 56;
part = "assembly";
side = "right";              // "right" or "left"; used by assembly preview
exploded = 0;                 // preview separation, 0 for nominal assembly
lens_preset = "budget_25x45"; // "budget_25x45" or "compact_23x30"
show_rear_pod = true;          // assembly preview only

// ---------- Printer and fastener allowances ----------
WALL = 1.2;                   // three 0.4 mm perimeters
FIT = 0.25;                   // general FDM sliding clearance, per side
EPS = 0.02;
M2_CLEAR_D = 2.5;
M2_PILOT_D = 1.8;
M25_CLEAR_D = 2.9;
M25_PILOT_D = 2.1;
M2_WASHER_T = 0.30;
M2_NYLOC_H = 2.80;
M2_THREAD_PROTRUSION = 0.80; // two full 0.4 mm pitches beyond the locknut

// ---------- Concrete v0.1 budget optics ----------
// The required/BOM-default lens is the EUR 1.50, 25 mm / +45 mm biconvex
// acrylic lens. The optional compact lens shortens the engine but costs more.
// The budget preset uses the central 48 x 32 viewport on the 28 mm-clear,
// 45-degree combiner. The compact preset is retained for experiments only.
LENS_D = lens_preset == "budget_25x45" ? 25.0 : 23.0;
// Conservative image-side tapered stops trade brightness/eye box for a pane
// footprint with decentre margin. The exact oblique asserts below govern fit.
LENS_CLEAR_D = lens_preset == "budget_25x45" ? 15.0 : 10.0;
LENS_FL = lens_preset == "budget_25x45" ? 45.0 : 30.0;
LENS_TO_COMBINER = 15.0;
LENS_EDGE_T = lens_preset == "budget_25x45" ? 1.2 : 1.5;
LENS_CENTER_T = 5.0;          // provisional; measure the actual lens
// Measure each crown height independently from its own rim plane. Never infer
// these from centre thickness alone: an asymmetric biconvex lens can put most
// of its sag on the stop-facing/front surface.
LENS_FRONT_SAG = lens_preset == "budget_25x45" ? 1.90 : 1.75;
LENS_REAR_SAG = lens_preset == "budget_25x45" ? 1.90 : 1.75;
LENS_MEASUREMENT_CLOSURE_TOL = 0.20; // cheap depth-gauge/caliper stack-up
LENS_POCKET_DIAMETRAL_CLEAR = 0.30;
LENS_RETAINER_T = 2.4;
LENS_PAD_D = 1.6;
LENS_PAD_R = LENS_D / 2 + 0.1;
LENS_PAD_GAP = 0.6;           // fill with 0.7--0.8 mm silicone/TPU/foam dots
LENS_FRONT_PAD_LENGTH = 0.4;
LENS_REAR_PAD_X = LENS_EDGE_T + LENS_PAD_GAP;
LENS_SURFACE_CLEAR = 0.6;     // rear full-diameter relief beyond centre apex
LENS_RELIEF_END_X = LENS_EDGE_T + LENS_REAR_SAG + LENS_SURFACE_CLEAR;
// Explicit provisional packaging/focus-start datum. It is not derived from
// the sag values and is not a claim about the thick lens's principal planes.
// Establish the real OLED position on the focus bench.
LENS_PRINCIPAL_FROM_FRONT_RIM = lens_preset == "budget_25x45" ? 0.60 : 0.75;
LENS_FRONT_RADIUS = ((LENS_D / 2) * (LENS_D / 2)
                     + LENS_FRONT_SAG * LENS_FRONT_SAG)
                    / (2 * max(LENS_FRONT_SAG, EPS));
LENS_REAR_RADIUS = ((LENS_D / 2) * (LENS_D / 2)
                    + LENS_REAR_SAG * LENS_REAR_SAG)
                   / (2 * max(LENS_REAR_SAG, EPS));

// Exact axial clearance between the spherical front surface and the linearly
// tapered aperture. Its minimum can occur inside the taper, so checking only
// the narrow aperture edge is not conservative.
function lens_front_surface_x(radius) =
    sqrt(max(0, LENS_FRONT_RADIUS * LENS_FRONT_RADIUS
                - (LENS_D / 2) * (LENS_D / 2)))
    - sqrt(max(0, LENS_FRONT_RADIUS * LENS_FRONT_RADIUS
                  - radius * radius));
function lens_taper_slope(plate_t) =
    (plate_t - LENS_PAD_GAP - LENS_FRONT_PAD_LENGTH)
    / ((LENS_D + LENS_POCKET_DIAMETRAL_CLEAR) / 2 - LENS_CLEAR_D / 2);
function lens_taper_wall_x(radius, plate_t) =
    -plate_t + lens_taper_slope(plate_t)
    * (radius - LENS_CLEAR_D / 2);
function lens_gap_at_radius(radius, plate_t) =
    lens_front_surface_x(radius) - lens_taper_wall_x(radius, plate_t);
function lens_gap_critical_radius(plate_t) =
    let(slope = lens_taper_slope(plate_t),
        stationary = slope * LENS_FRONT_RADIUS / sqrt(1 + slope * slope))
    min(LENS_D / 2, max(LENS_CLEAR_D / 2, stationary));
function lens_min_hard_gap(plate_t) =
    min(lens_gap_at_radius(LENS_CLEAR_D / 2, plate_t),
        lens_gap_at_radius(LENS_D / 2, plate_t),
        lens_gap_at_radius(lens_gap_critical_radius(plate_t), plate_t));

FOCUS_MIN = lens_preset == "budget_25x45" ? 38.0 : 24.0;
FOCUS_MAX = lens_preset == "budget_25x45" ? 52.0 : 34.0;
FOCUS_NOMINAL = lens_preset == "budget_25x45" ? 45.0 : 29.0;

COMBINER_PANE = [30.0, 30.0, 1.1];
COMBINER_CLEAR = [28.0, 28.0];
COMBINER_ANGLE = 45.0;
COMBINER_FRAME_RIM = 2.0;
COMBINER_BASE_T = 1.6;
COMBINER_CLAMP_T = 1.4;
COMBINER_PANE_GAP = 0.15;
PANE_SLOT_CLEAR = 0.20;
COMBINER_SHIM_T = 0.30;
COMBINER_CORNER_R = 2.0;
COMBINER_EDGE_LINER_T = 0.80; // nominal fitted radial thickness, soft material
COMBINER_EDGE_LINER_INTERFERENCE = 0.10; // per side before TPU stretch
COMBINER_EDGE_LINER_CLEAR = 0.20; // per side to the rigid locator rails
COMBINER_EDGE_LINER_FACE_RECESS = 0.10;
COMBINER_EDGE_LINER_CORNER_RELIEF_R = 0.35;
COMBINER_LOCATOR_W = 1.10;
COMBINER_EDGE_LINER_FREE_INNER = COMBINER_PANE[0]
                                 - 2 * COMBINER_EDGE_LINER_INTERFERENCE;
COMBINER_EDGE_LINER_FREE_OUTER = COMBINER_EDGE_LINER_FREE_INNER
                                 + 2 * COMBINER_EDGE_LINER_T;
COMBINER_EDGE_LINER_FITTED_OUTER = COMBINER_PANE[0]
                                   + 2 * COMBINER_EDGE_LINER_T;
PANE_LOCATOR_GAP = COMBINER_PANE[0]
                   + 2 * (COMBINER_EDGE_LINER_T
                          + COMBINER_EDGE_LINER_CLEAR);
PANE_WORST_LATERAL_PLAY = 0.25; // liner clearance plus plausible compression

// ---------- OLED cartridge ----------
// Waveshare 0.49 inch module reference. Measure thickness, active-area offset,
// and cable exit on the actual module before printing the final cartridge.
OLED_PCB = [3.0, 15.5, 13.0]; // [thickness along X, long Y, high Z]
OLED_ACTIVE = [9.92, 4.96];    // verify on the sourced display
OLED_RESOLUTION = [64, 32];
OLED_VIEWPORT = [48, 32];       // central columns; firmware viewport must match
OLED_WINDOW = [11.5, 6.5];    // [Y, Z], deliberately generous
OLED_WINDOW_OFFSET = [0.0, 0.0];
OLED_CART_DEPTH = OLED_PCB[0] + 2 * WALL;
// Square guide body closely tracks the lens tunnel so the OLED cannot yaw.
OLED_CART_Y = max(OLED_PCB[1] + 2 * WALL + 2 * FIT, LENS_D);
OLED_CART_Z = max(OLED_PCB[2] + 2 * WALL + 2 * FIT, LENS_D);
OLED_FACE_X = WALL;
OLED_LOCK_X = OLED_CART_DEPTH - 1.5;
OLED_LOCK_Z = OLED_CART_Z / 2 - 2.5;

// ---------- Tunnel ----------
TUNNEL_INNER = max(LENS_D + 0.5, OLED_CART_Y + 2 * FIT);
TUNNEL_OUTER = TUNNEL_INNER + 2 * WALL;
TUNNEL_LENGTH = LENS_PRINCIPAL_FROM_FRONT_RIM + FOCUS_MAX
                - OLED_FACE_X + OLED_CART_DEPTH + 2.0;
FOCUS_SLOT_X0 = LENS_PRINCIPAL_FROM_FRONT_RIM + FOCUS_MIN
                - OLED_FACE_X + OLED_LOCK_X;
FOCUS_SLOT_X1 = LENS_PRINCIPAL_FROM_FRONT_RIM + FOCUS_MAX
                - OLED_FACE_X + OLED_LOCK_X;
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

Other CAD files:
hardware/cad/stl/fit_coupon.stl
hardware/cad/stl/focus_bench_jig.stl
hardware/cad/stl/cut_template_print.stl
hardware/cad/stl/rear_pod.stl
hardware/cad/stl/combiner_clamp.stl

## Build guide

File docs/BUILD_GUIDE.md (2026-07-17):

# Build guide

Read [SAFETY.md](SAFETY.md) first. The safest and fastest path is to prove the
optics on a bench, then print the wearable parts. A beautiful glasses clip
cannot rescue an unreadable combiner.

## Tools and skills

- FDM printer with black PETG and optionally TPU
- fine-tip temperature-controlled soldering iron, flux, solder, side cutters
- multimeter with continuity and DC voltage modes
- small screwdrivers, M2 and M2.5 hardware, heat-shrink, tweezers
- digital calipers plus a clean straightedge/depth-gauge fixture for lens sag
- lens cloth, nitrile gloves, black flocking tape or matte paint
- a phone/camera with manual infinity focus for optical setup

This is a moderate soldering and optical-alignment project, not a no-tools kit.
Practice on scrap wire before soldering the XIAO battery pads.

## 1. Buy and inspect the parts

Order the required rows in [the BOM](../hardware/bom.csv). The 25 mm / 45 mm
budget reference has **$46.59 of known line-item cost**. The splitter listing
included delivery when researched, but electronics/lens shipping and tax remain
unresolved. Combine electronics orders, reuse consumable scraps, and check the
actual cart total. Tooling and full packs/spools of generic consumables are not
included; the under-$50 delivered target is not yet demonstrated by a build
report.

When the parts arrive:

1. Photograph labels and measure the OLED board, emitting-area centre,
   connector, lens diameter, rim/centre thickness, both face crown sags,
   combiner thickness, cell, button body/stem, and glasses temple. Support each
   lens rim plane on a clean depth fixture and measure its crown independently;
   do not infer symmetry from centre thickness. Edge thickness plus both sags
   must close to centre thickness within the CAD's 0.20 mm allowance.
2. Mark the lens face chosen to point toward the image-side stop on removable
   rim tape. Enter that face as `LENS_FRONT_SAG` and the OLED-side face as
   `LENS_REAR_SAG`.
3. Compare the cell charge rating with the XIAO's 380 mA charger. Do not proceed
   if the rating is unknown or lower.
4. Mark the combiner's coated/reflective face using removable tape on its frame,
   never ink or adhesive on the optical area.
5. Edit the parameters at the top of `hardware/cad/openglasshole.scad` before
   exporting final parts.

## 2. Prove the OLED and firmware on USB

Wire only the OLED and button according to the
[schematic](../hardware/electronics/schematic.svg). Leave the battery disconnected.

The OLED cable labels are authoritative:

```text
OLED VCC → XIAO 3V3     OLED SDA → XIAO D4 / GPIO6
OLED GND → XIAO GND     OLED SCL → XIAO D5 / GPIO7
button   → XIAO D2 and GND
```

Install PlatformIO, copy the configuration, and build:

```sh
cp firmware/include/config.example.h firmware/include/config.h
pio run --project-dir firmware
pio run --project-dir firmware --target upload
pio device monitor --baud 115200
```

Because VS Code is running as a Flatpak on the reference workstation, USB serial
may be easier from a normal host terminal. If the extension cannot see the
XIAO, do not change device permissions blindly; use the host PlatformIO CLI or
grant only the relevant USB/serial access through Flatseal.

The text must appear mirrored on a directly viewed OLED when `MIRROR_X=true`;
the combiner reflection makes it readable. If the panel is blank, confirm `0x3c`
with an I²C scanner and use this repository's driver—the module's visible RAM
starts at column `0x20`, unlike many generic SSD1306 examples.

## 3. Run the cue server

On a laptop or Raspberry Pi connected to the same 2.4 GHz LAN:

```sh
export OPENGLASSHOLE_API_KEY='replace-with-a-long-random-key'
python3 server/cue_server.py --host 0.0.0.0 --port 8787
```

Find that computer's LAN address, put it in `CUE_URL` inside the private
`firmware/include/config.h`, flash again, then open the displayed editor URL on
a phone. Send a short cue and verify it updates within the configured poll
interval. See [API.md](API.md) for curl and HTTPS options.

## 4. Print the calibration parts

Start with:

- `fit_coupon.stl`
- `focus_bench_jig.stl`
- `oled_cartridge.stl`
- `lens_tunnel.stl`
- `lens_retainer.stl`
- `combiner_frame.stl`
- `combiner_clamp.stl`
- `combiner_shim.stl` (TPU or trace the pattern into soft foam)
- `combiner_edge_liner.stl` (soft TPU or cast/cut silicone; never rigid plastic)

Recommended first print settings are black PETG, 0.2 mm layers, 0.4 mm nozzle,
three perimeters, four top/bottom layers, and 25% gyroid infill. Use no supports
unless the slicer preview shows an unsupported bridge. Keep optical interiors
matte; shiny black plastic still reflects.

Print the lens retainer with its smaller aperture face on the bed. The opening
widens toward the full-diameter counterbore, keeping the taper self-supporting;
confirm the three tiny crescent lands remain distinct in the sliced preview.

Check the coupon. Aim for 0.20–0.30 mm sliding clearance per mating side,
0.20–0.30 mm diametral lens clearance, and combiner thickness plus 0.15–0.25 mm.
Adjust CAD parameters and reprint the coupon before the long parts.

## 5. Bench-focus the optical engine

1. Fit the OLED without glue on the emitting window and provide cable strain
   relief. Black tape around the board may seal stray light, but not cover parts
   that warm up.
2. Install the lens with the measured/entered front face toward the image-side
   stop. Apply nominally 0.7–0.8 mm removable silicone, TPU, or
   closed-cell-foam dots
   to the three front and three rear printed lands. Measure the actual lens rim
   and compressed pads: together they must lightly fill the modeled land
   spacing without preload or rattle. The image-side tapered aperture opens
   into a full-diameter counterbore before the lands and must not touch either
   convex surface; never tighten the retainer enough to flex or point-load it.
3. Dry-fit `combiner_edge_liner` around all four pane edges and corners first.
   Its one-piece soft collar must stay below both coated faces. Lower pane and
   liner into the frame together and confirm no bare edge can touch a rigid
   rail. Then add the separate `combiner_shim` face gasket in soft TPU/foam.
   Never use rigid PETG/PLA for either soft part, never glue the coating, and put
   the coated face toward the incoming OLED beam.
4. Place the OLED emitting plane near the lens BFL and leave the lock screw loose.
5. Put an infinity-focused camera at the eye datum. Aim past the combiner at a
   target at least several metres away.
6. Move the OLED sled until cue and target are simultaneously sharp. Check the
   centre first, then accept that a single cheap lens will have blurry edges.
7. Lock focus and map the usable eye box by moving the camera left/right/up/down.
   Target at least 6×6 mm while the complete central 48×32 cue remains visible.
   Reject or rework the wearable if the bench cannot meet that threshold.
8. Test both OLED rotations while the loose module is safely supported on the
   bench if a polarized lens makes the cue dim. The reference cartridge does
   not accept a 90° board rotation: swap the measured PCB/window Y/Z parameters
   and reprint a matching cartridge before assembly.

If the image never becomes sharp, confirm the emitting plane—not the PCB—is at
the focal distance. If it is sharp but doubled, reverse the plate or use a
thinner/first-surface combiner. If it is readable only in darkness, add the
opaque contrast flag or a higher-reflectance combiner.

## 6. Assemble the wearable

Only after the optical bench succeeds, print `temple_saddle`, `quick_release`,
`mount_adapter`, `engine_cradle`, `engine_clamp`, `combiner_bracket`, `rear_pod`,
`rear_pod_lid`, and `rear_button_retainer`. Print the button retainer flat on a
broad face and deburr its open U-slot without thinning the side bearings. Use a
removable opaque card or soft cover as a sunlight/storage flag until a validated
printed flag is added.

Do not orient `combiner_bracket` like the bench lens retainer: its pane socket
projects beyond the narrow stop plane. Put its square tunnel-interface,
full-pocket face on the bed with the socket rising. Add removable support from
the build plate inside the narrowing lens aperture and beneath the socket
arm/capture boss, keeping support off the three pad lands where possible. After
cleanup, verify the 15 mm aperture, undamaged lands, and at least 0.6 mm hard
clearance to the measured lens surface. Reject or redesign a print whose
support scars intrude into the lens cell.

1. Line the saddle with 1 mm TPU/silicone and strap it to the glasses temple
   using two separate 6–8 mm hook-and-loop bands. Nothing clamps the
   prescription lens; the bands are the intended snag-releasing element, not a
   certified breakaway.
2. Before fitting the engine, use two M2×5 socket-head screws (head no larger
   than 4.4 mm OD × 2.0 mm high) through the adapter's recessed X holes into the
   carriage's blind pilots. Trim every printed pilot with the matching tap or
   screw; do not force a splitting print.
3. Put the tunnel in the split collar and fasten the lower cradle to the upper
   clamp with two M2×6 screws. Put the adapter below the raised engine-clamp pad
   and fasten its Y pair with two more M2×6 screws. Slide the carriage onto the
   saddle and lock it with the side-access M2.5×6 set screw. The rail adjusts
   fore/aft only; set height/yaw/elevation by repositioning the padded saddle
   or by measured wedge shims, then re-run the optical test.
4. Fit the guarded combiner sandwich into the bracket socket. With both screw
   heads on the clamp/outboard face, use an M2×12 bolt through the 7.25 mm
   bracket-captured lower-ear stack and an M2×10 through the 4.25 mm upper-ear
   stack. Put a ≤5.0 mm OD washer and ordinary approximately 2.8 mm-high M2
   nyloc on each base/bracket side; each bolt must extend at least two complete
   0.4 mm thread pitches past its locknut. Before inserting the pane, verify the
   actual hardware preserves at least the modeled worst-case 1.05 mm gap to
   glass and 0.25 mm to the fitted liner. Keep at least 2.5 mm dynamic clearance
   from prescription lenses through deliberate frame flex. The pane's chief-ray
   point is centred on the chosen pupil and occupies that eye's normal
   sightline; keep the other eye unobstructed.
5. Route the four OLED wires above the temple hinge with a service loop and at
   least a 5 mm bend radius. Confirm the glasses can fold without pinching them.
6. Strap the rear pod to the temple with the remaining two independent bands,
   then mount the XIAO and external antenna. Both complete strap footprints must
   wrap the temple; keep the antenna away from the cell and metal hardware.
7. Wire the long-stem button, insert it stem-first from the lid underside, and
   slide `rear_button_retainer` under its body from the cage's open `+Y` side
   until it stops on both ledges. Kapton may prevent withdrawal/rattle but must
   not carry button force. Confirm repeated presses react against the printed
   plate, not tape, solder joints, or the controller.
8. Solder the protected cell through SW1 only after confirming polarity twice.
   The cell must float in its pocket with padding and strain relief; no screw may
   touch it.
9. Fit the lid and record optical-head, rear-pod, and total mass. The preliminary
   all-on-glasses estimate is roughly 55–65 g, not a measured claim. If it
   slides or pressure is uncomfortable, put the controller/cell pod in a
   collar or pocket. Add the BOM's optional low-retention inline connector near
   the glasses and prove on a surrogate frame that a cable pull disconnects it;
   a long tether to the face is not acceptable.

## 7. Charge and acceptance test

Remove the glasses, place them on a nonflammable surface, switch SW1 ON, then
connect USB-C. Attend the first full charge and check repeatedly for heat or
swelling. Do not wear while charging.

Before normal use, pass these checks:

- cue and distant target are comfortable at the same eye focus
- central-48×32 full-cue eye box is at least approximately 6×6 mm
- the soft radial collar covers all pane edges/corners, the face gasket prevents
  rattle, and no glass touches a rigid rail or fastener
- measured lens-to-stop hard clearance is at least 0.6 mm, and dynamic
  prescription-lens clearance is at least 2–3 mm
- mount aim drifts less than about 0.5° after repeated nodding
- an off-head pull test on a surrogate/spare frame shows the padded
  hook-and-loop mount peels free before the frame is overstressed; never perform
  a deliberate snag test while wearing it
- wire is not pinched when glasses fold
- both rear-pod straps fully wrap the temple, and 50 button presses cause no
  switch/retainer movement, lead strain, or tape loading
- short and two-hour stationary comfort tests are acceptable
- update, Wi-Fi outage, server outage, pause, and reload all preserve a readable
  cached cue
- actual current and runtime are measured and recorded

## Troubleshooting

| Symptom | Likely cause | Check |
| --- | --- | --- |
| OLED blank | wrong driver RAM columns or I²C wiring | address `0x3c`, D4/D5, repository driver |
| Text reversed | combiner handedness differs | toggle `MIRROR_X` / `MIRROR_Y` |
| Cue sharp, world blurry | eye/camera focused near | move OLED toward the calibrated virtual-distance position |
| No focus anywhere | wrong BFL or emitting-plane datum | extend sled range; measure from active pixels |
| Double image | second pane-surface reflection | coated face toward beam; thinner pane; first-surface splitter |
| Image disappears with sunglasses | crossed polarization | rotate OLED 90° and refocus |
| Tiny eye box | viewport, alignment, eye relief, or small aperture | keep the central-48 crop; improve alignment; reduce eye relief; use a larger matched lens/combiner |
| Cue freezes during fetch | slow/weak Wi-Fi | increase poll interval, improve antenna placement, cache full cue |
| Battery drains quickly | radio remains connected or high contrast | radio-off setting, server reachability, measure current |
| Charge never starts | reference switch topology | set SW1 ON; recheck battery polarity and rating |

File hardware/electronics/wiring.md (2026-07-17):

# Wiring and power

The reference build is point-to-point wiring. It deliberately avoids a custom
PCB and a separate charger. See [schematic.svg](schematic.svg) for the full
diagram.

## Pin map

| Function | XIAO label | ESP32-C3 GPIO | Connect to |
| --- | --- | --- | --- |
| OLED data | D4 / SDA | GPIO6 | OLED SDA |
| OLED clock | D5 / SCL | GPIO7 | OLED SCL |
| Pause/fetch button | D2 | GPIO4 | Button, then GND |
| OLED power | 3V3 | — | OLED VCC |
| Common return | GND | — | OLED GND, button, battery negative |
| Battery positive | BAT+ pad | — | Protected LiPo positive through SW1 |
| Battery negative | BAT− pad | — | Protected LiPo negative |

The Waveshare cable pin labels, not cable colours, are authoritative. Cable
colours can change between batches. Verify every connection and LiPo polarity
with a multimeter before plugging in USB or connecting the battery.

## Why this power path

The XIAO contains a single-cell charger specified by Seeed at 380 mA. The
reference 500 mAh protected cell accepts up to 500 mA charging, so the two are
compatible on paper. SW1 sits in series with battery positive; this is the
fewest-part topology, but it means **SW1 must be ON to charge the battery**.
USB-C can still power and flash the board while SW1 is OFF.

Do not add a common 1 A TP4056 module. It duplicates the charger and its default
current can exceed a small cell's safe charge rate.

The XIAO ESP32-C3 uses its included external antenna. Snap it onto the U.FL
connector before fitting the rear cover and keep the antenna clear of the LiPo,
wires, and metal fasteners.

## Assembly checks

1. With battery disconnected, check there is no short between 3V3 and GND.
2. Confirm BAT+ and BAT− at both ends of the pigtail; never trust JST colours or
   connector orientation alone.
3. Power over USB first. Confirm the OLED is detected at I²C address `0x3c`.
4. Disconnect USB. Connect the protected LiPo with SW1 OFF, then switch ON.
5. Charge on a nonflammable surface while the device is off your head. A normal
   full charge should take roughly 1.5–2 hours including the CV taper.

Short Wi-Fi transmit peaks can exceed 300 mA at the chip. Use short power wires
and the documented reference cell, which is rated for 500 mA continuous
discharge. Verify peak stability and actual current on the finished build before
wearing it. Replace, do not reuse, any swollen, creased, punctured, hot, or
damaged cell.

## Optional OLED hard-off

The base design uses the physical switch for true off. For deep standby without
switching the whole unit off, a high-side P-channel MOSFET can disconnect OLED
VCC. That option is intentionally not in the baseline schematic or firmware:
it needs careful gate logic and I²C pins must go high-impedance before power is
cut to avoid phantom powering the OLED.

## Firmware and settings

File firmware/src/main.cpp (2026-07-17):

#include <Arduino.h>
#include <HTTPClient.h>
#include <Preferences.h>
#include <WiFi.h>
#include <WiFiClientSecure.h>
#include <Wire.h>
#include <driver/gpio.h>
#include <esp_sleep.h>
#include <esp_wifi.h>
#include <esp32-hal-cpu.h>
#include <freertos/FreeRTOS.h>
#include <freertos/queue.h>
#include <freertos/task.h>

#if __has_include("config.h")
#include "config.h"
#else
#include "config.example.h"
#define OGH_USING_EXAMPLE_CONFIG 1
#endif

#include "oled49.h"

namespace {

constexpr uint8_t BUTTON_PIN = D2;  // XIAO D2 / GPIO4, active low.
constexpr uint8_t OLED_SDA_PIN = D4;  // XIAO D4 / GPIO6.
constexpr uint8_t OLED_SCL_PIN = D5;  // XIAO D5 / GPIO7.
constexpr uint32_t BUTTON_DEBOUNCE_MS = 30;
constexpr uint32_t BUTTON_FORCE_FETCH_MS = 1200;
constexpr uint32_t MAX_FAILURE_BACKOFF_MS = 60000;
constexpr uint32_t TLS_HANDSHAKE_TIMEOUT_SECONDS = 6;
constexpr size_t MAX_CUE_CHARS = 512;
constexpr size_t MAX_RESPONSE_BYTES = MAX_CUE_CHARS * 4U;
constexpr size_t MAX_ETAG_CHARS = 95;
constexpr uint32_t NETWORK_TASK_STACK_BYTES = 8192;
constexpr uint32_t SCROLL_START_HOLD_MS = 1200;
constexpr uint32_t SCROLL_END_HOLD_MS = 1800;
constexpr int16_t CHARACTER_WIDTH_PX = static_cast<int16_t>(6 * ogh_config::TEXT_SIZE);
constexpr int16_t LINE_HEIGHT_PX = static_cast<int16_t>(8 * ogh_config::TEXT_SIZE);
constexpr int16_t VIEWPORT_WIDTH_PX = ogh_config::OLED_VIEWPORT_WIDTH_PX;
constexpr int16_t VIEWPORT_X_PX = static_cast<int16_t>(
    (Oled49::WIDTH_PX - VIEWPORT_WIDTH_PX) / 2
);
constexpr size_t LINE_COLUMNS = static_cast<size_t>(VIEWPORT_WIDTH_PX / CHARACTER_WIDTH_PX);
constexpr size_t VISIBLE_ROWS = static_cast<size_t>(Oled49::HEIGHT_PX / LINE_HEIGHT_PX);
constexpr size_t MAX_WRAPPED_LINES = MAX_CUE_CHARS + 1U;

static_assert(ogh_config::TEXT_SIZE > 0, "TEXT_SIZE must be at least 1");
static_assert(VIEWPORT_WIDTH_PX > 0, "OLED viewport must be at least one pixel wide");
static_assert(VIEWPORT_WIDTH_PX <= Oled49::WIDTH_PX, "OLED viewport exceeds the panel width");
static_assert((Oled49::WIDTH_PX - VIEWPORT_WIDTH_PX) % 2 == 0,
              "OLED viewport must be centered on whole pixels");
static_assert(CHARACTER_WIDTH_PX <= VIEWPORT_WIDTH_PX,
              "TEXT_SIZE is too large for the OLED viewport");
static_assert(LINE_HEIGHT_PX <= Oled49::HEIGHT_PX, "TEXT_SIZE is too large for the OLED height");
static_assert(MAX_CUE_CHARS <= UINT16_MAX, "wrapped line offsets must fit uint16_t");

struct FetchResult {
    bool success;
    bool has_text;
    uint32_t poll_ms;
    uint32_t scroll_ms;
    char text[MAX_CUE_CHARS + 1];
    char etag[MAX_ETAG_CHARS + 1];
};

Oled49 display(
    Wire,
    ogh_config::OLED_I2C_ADDRESS,
    ogh_config::MIRROR_X,
    ogh_config::MIRROR_Y
);
Preferences preferences;

String cue_text = "OpenGlassHole ready";
String cue_etag;
uint16_t wrapped_line_starts[MAX_WRAPPED_LINES]{};
uint16_t wrapped_line_lengths[MAX_WRAPPED_LINES]{};
size_t wrapped_line_count = 0;
int32_t scroll_offset_px = 0;
int32_t max_scroll_offset_px = 0;
uint32_t scroll_ms = ogh_config::DEFAULT_SCROLL_MS;
uint32_t poll_ms = ogh_config::DEFAULT_POLL_SECONDS * 1000UL;
uint32_t next_frame_at = 0;
uint32_t next_poll_at = 0;
uint8_t consecutive_failures = 0;
bool paused = false;
bool force_redraw = true;
bool force_fetch = true;
bool fetch_in_progress = false;
bool fetch_once_satisfied = false;
QueueHandle_t fetch_results = nullptr;
String fetch_etag;
uint32_t fetch_default_poll_ms = poll_ms;
uint32_t fetch_default_scroll_ms = scroll_ms;

bool last_button_raw = HIGH;
bool button_stable = HIGH;
uint32_t button_changed_at = 0;
uint32_t button_pressed_at = 0;

bool deadlineReached(uint32_t now, uint32_t deadline) {
    return static_cast<int32_t>(now - deadline) >= 0;
}

uint32_t boundedHeader(const String &value, uint32_t minimum, uint32_t maximum, uint32_t fallback) {
    if (value.isEmpty()) {
        return fallback;
    }
    const long parsed = value.toInt();
    if (parsed < static_cast<long>(minimum) || parsed > static_cast<long>(maximum)) {
        return fallback;
    }
    return static_cast<uint32_t>(parsed);
}

String urlEncode(const char *input) {
    const char hex[] = "0123456789ABCDEF";
    String encoded;
    while (*input != '\0') {
        const uint8_t value = static_cast<uint8_t>(*input++);
        if ((value >= 'a' && value <= 'z') || (value >= 'A' && value <= 'Z') ||
            (value >= '0' && value <= '9') || value == '-' || value == '_' || value == '.') {
            encoded += static_cast<char>(value);
        } else {
            encoded += '%';
            encoded += hex[value >> 4];
            encoded += hex[value & 0x0F];
        }
    }
    return encoded;
}

String sanitizeCue(const String &input) {
    String output;
    output.reserve(min(input.length(), MAX_CUE_CHARS));
    bool pending_space = false;
    uint8_t pending_newlines = 0;
    for (size_t index = 0; index < input.length() && output.length() < MAX_CUE_CHARS; ++index) {
        const uint8_t value = static_cast<uint8_t>(input[index]);
        if ((value & 0xC0U) == 0x80U) {
            continue;  // Continuation byte for a non-ASCII glyph already replaced below.
        }
        char character = value >= 0x80U ? '?' : static_cast<char>(value);
        if (character == '\r' || character == '\n') {
            pending_newlines = min<uint8_t>(2, pending_newlines + 1);
            pending_space = false;
            if (character == '\r' && index + 1U < input.length() && input[index + 1U] == '\n') {
                ++index;  // Treat a CRLF pair as one explicit line break.
            }
            continue;
        }
        if (character == '\t' || character == ' ') {
            if (pending_newlines == 0) {
                pending_space = true;
            }
            continue;
        }
        if (character < 0x20 || character > 0x7E) {
            continue;
        }

        if (!output.isEmpty()) {
            while (pending_newlines > 0 && output.length() < MAX_CUE_CHARS) {
                output += '\n';
                --pending_newlines;
            }
            if (pending_newlines == 0 && pending_space && output.length() < MAX_CUE_CHARS) {
                output += ' ';
            }
        }
        if (output.length() >= MAX_CUE_CHARS) {
            break;
        }
        output += character;
        pending_space = false;
        pending_newlines = 0;
    }
    return output;
}

void appendWrappedLine(size_t start, size_t length) {
    if (wrapped_line_count >= MAX_WRAPPED_LINES) {
        return;
    }
    wrapped_line_starts[wrapped_line_count] = static_cast<uint16_t>(start);
    wrapped_line_lengths[wrapped_line_count] = static_cast<uint16_t>(length);
    ++wrapped_line_count;
}

void rebuildWrappedLayout() {
    wrapped_line_count = 0;
    const size_t cue_length = cue_text.length();
    size_t paragraph_start = 0;

    while (paragraph_start <= cue_length && wrapped_line_count < MAX_WRAPPED_LINES) {
        size_t paragraph_end = paragraph_start;
        while (paragraph_end < cue_length && cue_text[paragraph_end] != '\n') {
            ++paragraph_end;
        }

        size_t cursor = paragraph_start;
        if (cursor == paragraph_end) {
            appendWrappedLine(cursor, 0);
        }
        while (cursor < paragraph_end && wrapped_line_count < MAX_WRAPPED_LINES) {
            while (cursor < paragraph_end && cue_text[cursor] == ' ') {
                ++cursor;
            }
            if (cursor >= paragraph_end) {
                break;
            }

            const size_t remaining = paragraph_end - cursor;
            if (remaining <= LINE_COLUMNS) {
                appendWrappedLine(cursor, remaining);
                cursor = paragraph_end;
                continue;
            }

            const size_t hard_end = cursor + LINE_COLUMNS;
            size_t line_end = hard_end;
            size_t next_cursor = hard_end;
            if (cue_text[hard_end] == ' ') {
                next_cursor = hard_end + 1U;
            } else {
                for (size_t probe = hard_end; probe > cursor; --probe) {
                    if (cue_text[probe - 1U] == ' ') {
                        line_end = probe - 1U;
                        next_cursor = probe;
                        break;
                    }
                }
            }
            if (line_end == cursor) {
                line_end = hard_end;
                next_cursor = hard_end;
            }
            appendWrappedLine(cursor, line_end - cursor);
            cursor = next_cursor;
        }

        if (paragraph_end >= cue_length) {
            break;
        }
        paragraph_start = paragraph_end + 1U;
    }

    if (wrapped_line_count == 0) {
        appendWrappedLine(0, 0);
    }
    const int32_t content_height = static_cast<int32_t>(wrapped_line_count * LINE_HEIGHT_PX);
    max_scroll_offset_px = max<int32_t>(0, content_height - Oled49::HEIGHT_PX);
}

void resetCueScroll() {
    rebuildWrappedLayout();
    scroll_offset_px = 0;
    next_frame_at = millis() + SCROLL_START_HOLD_MS;
    force_redraw = true;
}

void setCueText(const String &incoming, bool persist) {
    const String cleaned = sanitizeCue(incoming);
    if (cleaned == cue_text) {
        return;
    }
    cue_text = cleaned;
    if (persist) {
        preferences.putString("cue", cue_text);
    }
    resetCueScroll();
}

void renderCue(bool advance) {
    const uint32_t now = millis();
    if (!force_redraw && (paused || max_scroll_offset_px == 0)) {
        return;
    }
    if (!force_redraw && !deadlineReached(now, next_frame_at)) {
        return;
    }
    const bool redraw_only = force_redraw;
    force_redraw = false;

    if (advance && !redraw_only && !paused && max_scroll_offset_px > 0) {
        if (scroll_offset_px < max_scroll_offset_px) {
            ++scroll_offset_px;
            next_frame_at = now + (
                scroll_offset_px == max_scroll_offset_px ? SCROLL_END_HOLD_MS : scroll_ms
            );
        } else {
            scroll_offset_px = 0;
            next_frame_at = now + SCROLL_START_HOLD_MS;
        }
    }

    display.clear();
    display.setTextColor(1);
    display.setTextSize(ogh_config::TEXT_SIZE);
    display.setTextWrap(false);

    size_t first_line = 0;
    int16_t y = 0;
    if (max_scroll_offset_px == 0) {
        const int16_t content_height = static_cast<int16_t>(wrapped_line_count * LINE_HEIGHT_PX);
        y = static_cast<int16_t>((Oled49::HEIGHT_PX - content_height) / 2);
    } else {
        first_line = static_cast<size_t>(scroll_offset_px / LINE_HEIGHT_PX);
        y = static_cast<int16_t>(-(scroll_offset_px % LINE_HEIGHT_PX));
    }

    const size_t last_line = min(wrapped_line_count, first_line + VISIBLE_ROWS + 1U);
    for (size_t line = first_line; line < last_line; ++line) {
        const size_t start = wrapped_line_starts[line];
        const size_t end = start + wrapped_line_lengths[line];
        const int16_t line_width = static_cast<int16_t>(
            wrapped_line_lengths[line] * static_cast<size_t>(CHARACTER_WIDTH_PX)
        );
        const int16_t x = static_cast<int16_t>(
            VIEWPORT_X_PX + (VIEWPORT_WIDTH_PX - line_width) / 2
        );
        display.setCursor(x, y);
        for (size_t index = start; index < end; ++index) {
            display.write(static_cast<uint8_t>(cue_text[index]));
        }
        y = static_cast<int16_t>(y + LINE_HEIGHT_PX);
    }
    display.show();
}

void setRadioOff() {
    WiFi.disconnect(true, false);
    WiFi.mode(WIFI_OFF);
}

bool connectWifi() {
    if (WiFi.status() == WL_CONNECTED) {
        return true;
    }
    WiFi.mode(WIFI_STA);
    WiFi.setSleep(true);
    WiFi.begin(ogh_config::WIFI_SSID, ogh_config::WIFI_PASSWORD);
    const uint32_t started_at = millis();
    while (WiFi.status() != WL_CONNECTED && millis() - started_at < ogh_config::WIFI_CONNECT_TIMEOUT_MS) {
        delay(10);  // The loop task keeps rendering while this network task yields.
    }
    if (WiFi.status() != WL_CONNECTED) {
        if (ogh_config::RADIO_OFF_BETWEEN_POLLS) {
            setRadioOff();
        }
        return false;
    }
    esp_wifi_set_ps(WIFI_PS_MAX_MODEM);
    return true;
}

template <typename Client>
bool performFetch(
    Client &client,
    const String &url,
    const String &request_etag,
    bool allow_bearer,
    FetchResult &result
) {
    HTTPClient request;
    request.setConnectTimeout(5000);
    request.setTimeout(4000);
    if (!request.begin(client, url)) {
        return false;
    }
    const char *response_headers[] = {"ETag", "X-Poll-Seconds", "X-Scroll-Ms"};
    request.collectHeaders(response_headers, 3);
    request.setUserAgent("OpenGlassHole/0.1");
    if (!request_etag.isEmpty()) {
        request.addHeader("If-None-Match", request_etag);
    }
    // Never send a credential over cleartext HTTP, even if a user
    // accidentally leaves BEARER_TOKEN configured while testing on a LAN.
    if (allow_bearer && strlen(ogh_config::BEARER_TOKEN) > 0) {
        request.addHeader("Authorization", String("Bearer ") + ogh_config::BEARER_TOKEN);
    }

    const int status = request.GET();
    if (status != HTTP_CODE_OK && status != HTTP_CODE_NOT_MODIFIED) {
        request.end();
        return false;
    }

    const uint32_t server_poll_seconds = boundedHeader(
        request.header("X-Poll-Seconds"), 2, 3600, result.poll_ms / 1000UL
    );
    result.poll_ms = server_poll_seconds * 1000UL;
    result.scroll_ms = boundedHeader(request.header("X-Scroll-Ms"), 25, 500, result.scroll_ms);

    if (status == HTTP_CODE_OK) {
        const int content_length = request.getSize();
        // The bundled server always supplies Content-Length. Requiring it here
        // rejects indefinite/chunked bodies and gives the response a hard RAM
        // and radio-time bound before getString() allocates anything.
        if (content_length < 0 || content_length > static_cast<int>(MAX_RESPONSE_BYTES)) {
            request.end();
            return false;
        }
        const String body = request.getString();
        if (body.length() != static_cast<size_t>(content_length) ||
            body.length() > MAX_RESPONSE_BYTES) {
            request.end();
            return false;
        }
        const String cleaned = sanitizeCue(body);
        cleaned.toCharArray(result.text, sizeof(result.text));
        result.has_text = true;
        const String next_etag = request.header("ETag");
        if (!next_etag.isEmpty()) {
            next_etag.toCharArray(result.etag, sizeof(result.etag));
        }
    }
    request.end();
    return true;
}

bool fetchCue(FetchResult &result) {
    if (!connectWifi()) {
        return false;
    }
    String url = ogh_config::CUE_URL;
    url += url.indexOf('?') >= 0 ? '&' : '?';
    url += "device=";
    url += urlEncode(ogh_config::DEVICE_ID);

    bool success = false;
    if (url.startsWith("https://")) {
        if (strlen(ogh_config::TLS_ROOT_CA) == 0) {
            Serial.println("HTTPS refused: TLS_ROOT_CA is empty");
        } else {
            WiFiClientSecure secure_client;
            secure_client.setCACert(ogh_config::TLS_ROOT_CA);
            secure_client.setHandshakeTimeout(TLS_HANDSHAKE_TIMEOUT_SECONDS);
            success = performFetch(secure_client, url, fetch_etag, true, result);
        }
    } else if (url.startsWith("http://")) {
        WiFiClient client;
        success = performFetch(client, url, fetch_etag, false, result);
    } else {
        Serial.println("CUE_URL must start with http:// or https://");
    }

    if (ogh_config::RADIO_OFF_BETWEEN_POLLS) {
        setRadioOff();
    }
    return success;
}

void networkTask(void *) {
    FetchResult result{};
    result.poll_ms = fetch_default_poll_ms;
    result.scroll_ms = fetch_default_scroll_ms;
    result.success = fetchCue(result);
    xQueueOverwrite(fetch_results, &result);
    vTaskDelete(nullptr);
}

void scheduleNextPoll(bool success) {
    const uint32_t now = millis();
    if (success) {
        consecutive_failures = 0;
        next_poll_at = now + poll_ms;
        return;
    }
    consecutive_failures = min<uint8_t>(consecutive_failures + 1, 6);
    const uint32_t backoff = min<uint32_t>(
        MAX_FAILURE_BACKOFF_MS,
        2000UL << (consecutive_failures - 1)
    );
    next_poll_at = now + max(poll_ms, backoff);
}

void startFetch() {
    fetch_etag = cue_etag;
    fetch_default_poll_ms = poll_ms;
    fetch_default_scroll_ms = scroll_ms;
    fetch_in_progress = true;
    const BaseType_t created = xTaskCreate(
        networkTask,
        "cue-fetch",
        NETWORK_TASK_STACK_BYTES,
        nullptr,
        1,
        nullptr
    );
    if (created != pdPASS) {
        fetch_in_progress = false;
        scheduleNextPoll(false);
        Serial.println("Could not create cue network task");
    }
}

void processFetchResult() {
    FetchResult result{};
    if (fetch_results == nullptr || xQueueReceive(fetch_results, &result, 0) != pdTRUE) {
        return;
    }
    fetch_in_progress = false;
    if (result.success) {
        fetch_once_satisfied = true;
        poll_ms = result.poll_ms;
        scroll_ms = result.scroll_ms;
        if (result.has_text) {
            setCueText(String(result.text), true);
        }
        if (result.etag[0] != '\0' && cue_etag != result.etag) {
            cue_etag = result.etag;
            preferences.putString("etag", cue_etag);
        }
    } else if (ogh_config::FETCH_ON_BOOT_ONLY) {
        // A boot/manual fetch that fails keeps retrying with backoff; once one
        // succeeds, automatic polling stops until the next long press.
        fetch_once_satisfied = false;
    }
    scheduleNextPoll(result.success);
}

void handleButton() {
    const uint32_t now = millis();
    const bool raw = digitalRead(BUTTON_PIN);
    if (raw != last_button_raw) {
        last_button_raw = raw;
        button_changed_at = now;
    }
    if (raw == button_stable || now - button_changed_at < BUTTON_DEBOUNCE_MS) {
        return;
    }
    button_stable = raw;
    if (button_stable == LOW) {
        button_pressed_at = now;
        return;
    }

    const uint32_t held_ms = now - button_pressed_at;
    if (held_ms >= BUTTON_FORCE_FETCH_MS) {
        force_fetch = true;
    } else {
        paused = !paused;
        force_redraw = true;
    }
}

uint32_t timeUntil(uint32_t now, uint32_t deadline) {
    const int32_t remaining = static_cast<int32_t>(deadline - now);
    return remaining > 0 ? static_cast<uint32_t>(remaining) : 0;
}

void idleUntilNextWork() {
    if (fetch_in_progress || !ogh_config::RADIO_OFF_BETWEEN_POLLS ||
        WiFi.status() == WL_CONNECTED || digitalRead(BUTTON_PIN) == LOW) {
        delay(2);
        return;
    }

    const uint32_t now = millis();
    const bool automatic_polling_enabled = !ogh_config::FETCH_ON_BOOT_ONLY ||
        !fetch_once_satisfied;
    uint32_t wait_ms = automatic_polling_enabled
        ? timeUntil(now, next_poll_at)
        : 60000UL;
    if (!paused && max_scroll_offset_px > 0) {
        wait_ms = min(wait_ms, timeUntil(now, next_frame_at));
    }
    if (wait_ms <= 2) {
        delay(1);
        return;
    }

    // OLED RAM remains powered while the ESP32-C3 light-sleeps. GPIO4 wakes on
    // a button press; the timer wakes just before the next frame or poll.
    esp_sleep_enable_timer_wakeup(static_cast<uint64_t>(wait_ms - 1) * 1000ULL);
    esp_light_sleep_start();
}

}  // namespace

void setup() {
    Serial.begin(115200);
#if OGH_USING_EXAMPLE_CONFIG
    Serial.println("Using config.example.h; copy it to config.h and set Wi-Fi/server values");
#endif
    pinMode(BUTTON_PIN, INPUT_PULLUP);
    setCpuFrequencyMhz(80);
    gpio_wakeup_enable(static_cast<gpio_num_t>(BUTTON_PIN), GPIO_INTR_LOW_LEVEL);
    esp_sleep_enable_gpio_wakeup();
    WiFi.persistent(false);
    WiFi.mode(WIFI_OFF);
    WiFi.setHostname("openglasshole");

    preferences.begin("ogh", false);
    fetch_results = xQueueCreate(1, sizeof(FetchResult));
    if (fetch_results == nullptr) {
        Serial.println("Could not allocate cue result queue");
    }
    const String stored_cue = preferences.getString("cue", cue_text);
    cue_etag = preferences.getString("etag", "");
    setCueText(stored_cue, false);
    resetCueScroll();

    if (!display.begin(OLED_SDA_PIN, OLED_SCL_PIN)) {
        Serial.println("OLED not found at configured I2C address");
    }
    display.setContrast(ogh_config::OLED_CONTRAST);
    renderCue(false);
    next_poll_at = millis();
}

void loop() {
    processFetchResult();
    handleButton();
    renderCue(true);
    const uint32_t now = millis();
    const bool automatic_polling_enabled = !ogh_config::FETCH_ON_BOOT_ONLY ||
        !fetch_once_satisfied;
    const bool automatic_poll_due = automatic_polling_enabled &&
        deadlineReached(now, next_poll_at);
    if (!fetch_in_progress && fetch_results != nullptr && (force_fetch || automatic_poll_due)) {
        force_fetch = false;
        startFetch();
    }
    idleUntilNextWork();
}

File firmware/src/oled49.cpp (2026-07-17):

#include "oled49.h"

#include <cstring>

namespace {
constexpr uint8_t CONTROL_COMMAND = 0x00;
constexpr uint8_t CONTROL_DATA = 0x40;
constexpr uint16_t COLOR_INVERSE = 2;
constexpr uint8_t FIRST_VISIBLE_COLUMN = 0x20;
constexpr uint8_t LAST_VISIBLE_COLUMN = 0x5F;
constexpr uint8_t LAST_VISIBLE_PAGE = 0x03;
constexpr size_t I2C_DATA_CHUNK = 24;  // control byte + data stays below Wire's buffer limit.
}  // namespace

Oled49::Oled49(TwoWire &wire, uint8_t address, bool mirror_x, bool mirror_y)
    : Adafruit_GFX(WIDTH_PX, HEIGHT_PX),
      _wire(wire),
      _address(address),
      _mirror_x(mirror_x),
      _mirror_y(mirror_y) {}

bool Oled49::begin(int sda_pin, int scl_pin, uint32_t clock_hz) {
    _wire.begin(sda_pin, scl_pin, clock_hz);
    _wire.beginTransmission(_address);
    if (_wire.endTransmission() != 0) {
        return false;
    }

    // Based on Waveshare's published OLED_0in49 initialization sequence. Use
    // horizontal addressing because our framebuffer is page-major.
    const uint8_t init[] = {
        0xAE,                    // display off
        0x00, 0x12,             // legacy column nibble defaults
        0x40,                    // display start line 0
        0xB0,                    // page 0
        0x81, 0x60,             // contrast (overridden by caller)
        static_cast<uint8_t>(_mirror_x ? 0xA1 : 0xA0),
        0xA6,                    // normal pixels
        0xA8, 0x1F,             // 1/32 multiplex
        static_cast<uint8_t>(_mirror_y ? 0xC0 : 0xC8),
        0xD3, 0x00,             // no display offset
        0x20, 0x00,             // horizontal addressing
        0xD5, 0x80,             // oscillator / divide ratio
        0xD9, 0xF1,             // pre-charge
        0xDA, 0x12,             // COM pin configuration used by this module
        0xDB, 0x40,             // VCOMH
        0x8D, 0x14,             // charge pump on
        0xAF,                    // display on
    };
    commands(init, sizeof(init));
    clear();
    show();
    return true;
}

void Oled49::drawPixel(int16_t x, int16_t y, uint16_t color) {
    if (x < 0 || x >= WIDTH_PX || y < 0 || y >= HEIGHT_PX) {
        return;
    }
    const size_t index = static_cast<size_t>(x) + static_cast<size_t>(y / 8) * WIDTH_PX;
    const uint8_t mask = static_cast<uint8_t>(1U << (y & 7));
    if (color == COLOR_INVERSE) {
        _buffer[index] ^= mask;
    } else if (color != 0) {
        _buffer[index] |= mask;
    } else {
        _buffer[index] &= static_cast<uint8_t>(~mask);
    }
}

void Oled49::clear() {
    std::memset(_buffer, 0, sizeof(_buffer));
}

void Oled49::show() {
    const uint8_t window[] = {
        0x21, FIRST_VISIBLE_COLUMN, LAST_VISIBLE_COLUMN,
        0x22, 0x00, LAST_VISIBLE_PAGE,
    };
    commands(window, sizeof(window));

    size_t offset = 0;
    while (offset < sizeof(_buffer)) {
        const size_t count = min(I2C_DATA_CHUNK, sizeof(_buffer) - offset);
        _wire.beginTransmission(_address);
        _wire.write(CONTROL_DATA);
        _wire.write(_buffer + offset, count);
        _wire.endTransmission();
        offset += count;
    }
}

void Oled49::setContrast(uint8_t contrast) {
    const uint8_t values[] = {0x81, contrast};
    commands(values, sizeof(values));
}

void Oled49::setPowered(bool powered) {
    command(powered ? 0xAF : 0xAE);
}

void Oled49::command(uint8_t value) {
    _wire.beginTransmission(_address);
    _wire.write(CONTROL_COMMAND);
    _wire.write(value);
    _wire.endTransmission();
}

void Oled49::commands(const uint8_t *values, size_t count) {
    // Command streaming is supported, but individual transactions also work
    // with conservative SSD1315 breakout implementations.
    for (size_t index = 0; index < count; ++index) {
        command(values[index]);
    }
}

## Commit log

2026-07-17 Build the OpenGlassHole autocue prototype
    [bom.csv, combiner_bracket.stl, combiner_clamp.stl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]
2026-07-17 Use current GitHub Actions runtimes
